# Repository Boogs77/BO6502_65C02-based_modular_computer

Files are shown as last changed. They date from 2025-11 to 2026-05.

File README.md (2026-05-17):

# BO6502: 65C02-Based Modular Computer System






Technical overview of the **BO6502** core architecture. This system leverages the iconic 6502 instruction set with modern, high-reliability components from Western Design Center, Atmel, and Hitachi, offering a versatile platform for retro-computing enthusiasts.

---

## 🧠 Processing Core & System Control

The system is built around a modular 39-pin bus (36 signals + 3 spares) distributed via a robust backplane.

| Module | Type | Status | Description |
| :--- | :--- | :--- | :--- |
| **[CPU Module](https://github.com/Boogs77/BO6502/tree/main/BO6502%20CPU)** |  |  | Central Processing Unit W65C02S. |
| **[Reset & Clock](https://github.com/Boogs77/BO6502/tree/main/BO6502%20RESET)** |  |  | NE555 Reset and switchable clock (2MHz/1MHz/500kHz). |
| **[Backplate](https://github.com/Boogs77/BO6502/tree/main/BO6502%20BACKPLATE)** |  |  | The 39-pin bus backbone with voltage regulation. |
| **[Bridge Connector](https://github.com/Boogs77/BO6502/tree/main/BO6502%20CONNECTOR)** |  |  | Interconnect for daisy-chaining multiple backplates. |

---

## 💾 Memory Map & Storage

The system features a balanced 64KB memory architecture, divided between high-speed static RAM and non-volatile storage.

### [RAM Module](https://github.com/Boogs77/BO6502/tree/main/BO6502%20RAM) ($0000 - $7FFF)
* **Chip**: HITACHI **HM62256LP-12** (32KB SRAM).
* **Status**: 
* **Features**: Revision 02 includes **8 exclusion jumpers** (J-CS0 to J-CS7) to carve out space for I/O modules. Includes JP4 to bypass system clock triggering.
* **PCB**: [RAM_final_rev02](https://github.com/Boogs77/BO6502/blob/main/BO6502%20RAM/gallery/RAM_final_rev02.png?raw=true).

### [ROM Module](https://github.com/Boogs77/BO6502/tree/main/BO6502%20ROM) ($8000 - $FFFF)
* **Chip**: ATMEL **AT28C256** (32KB EEPROM).
* **Status**: 
* **Features**: Equipped with a **ZIF socket** for easy updates. The "Multi" version uses jumpers (J-CS3, CS4, CS5) to disable ROM in specific ranges for advanced peripherals.
* **PCBs**: [Base](https://github.com/Boogs77/BO6502_65C02-based_modular_computer/blob/main/BO6502%20ROM/gallery/ROM_final_rev01.png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) | [24K Test](https://github.com/Boogs77/BO6502_65C02-based_modular_computer/blob/main/BO6502%20ROM/gallery/ROM24k_final_rev01.png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) | [Multi-Selection](https://github.com/Boogs77/BO6502_65C02-based_modular_computer/blob/main/BO6502%20ROM/gallery/ROMmulti_final_rev01.png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).

---

## 🔌 Peripheral & I/O Addressing

Peripheral addressing is managed via **74LS138** decoders to ensure precise memory mapping and avoid bus contention.

| Module | Type | Status | Address | PCB Link |
| :--- | :--- | :--- | :--- | :--- |
| **[VDU Module](https://github.com/Boogs77/BO6502/tree/main/BO6502%20VDU)** |  |  | **$BXXX** | [VDU PCB](https://github.com/Boogs77/BO6502_65C02-based_modular_computer/blob/main/BO6502%20VDU/gallery/VDU_TMS_final_rev01.png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) |
| **[Serial I/O](https://github.com/Boogs77/BO6502/tree/main/BO6502%20SERIAL)** |  |  | **$CXXX** | [Serial PCB](https://github.com/Boogs77/BO6502_65C02-based_modular_computer/blob/main/BO6502%20SERIAL/gallery/Serial_final_rev03.png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) |
| **[SD Card](https://github.com/Boogs77/BO6502/tree/main/BO6502%20SDCard)** |  |  | **$D1BX** | [SD Card PCB](https://github.com/Boogs77/BO6502_65C02-based_modular_computer/blob/main/BO6502%20SDCard/gallery/SDcard_final_rev02%20v2.png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) |
| **[Standalone Keyb](https://github.com/Boogs77/BO6502/tree/main/BO6502%20KEYb)** |  |  | **$D18X** | [Keyboard PCB](https://github.com/Boogs77/BO6502/blob/main/BO6502%20KEYb/gallery/KEYb_final-rev01.png?raw=true) |
| **[Big LCD Module](https://github.com/Boogs77/BO6502/tree/main/BO6502%20BIGLCD)** |  |  | **$D19X** | [Big LCD Module](https://github.com/Boogs77/BO6502/blob/main/BO6502%20BIGLCD/README.md) |
| **[Legacy LCD/Keyb](https://github.com/Boogs77/BO6502/tree/main/BO6502%20LCD_KEYb)** |  |  | **$DXXX** | [Legacy PCB](https://github.com/Boogs77/BO6502/blob/main/BO6502%20LCD_KEYb/gallery/LCD_KEYb_final_rev02.png?raw=true) |

---

## 📺 Visual Output Tiers

* **Pro**: **TMS9918A** VDU Module with 32KB dedicated RAM. Supports NTSC Composite Out, Sprites, and 16 Colors.
* **Advanced**: **Toshiba T6963** Graphical LCD (160x128 Pixels).
* **Basic**: **Hitachi HD44780U** 16x2 Character LCD.

---

## 🛠 Diagnostic & Testing Tools

| Module | Type | Status | Function | PCB Link |
| :--- | :--- | :--- | :--- | :--- |
| **[Monitor Interface](https://github.com/Boogs77/BO6502/tree/main/BO6502%20MONITOR)** |  |  | Arduino Mega Bus Sniffer (Ben Eater style). | [Monitor PCB](https://github.com/Boogs77/BO6502/blob/main/BO6502%20MONITOR/gallery/MONITOR_final_rev01.png?raw=true) |
| **[LED Test Board](https://github.com/Boogs77/BO6502/tree/main/BO6502%20LED)** |  |  | Visual 16-LED debug for VIA 65C22 ports. | [LED PCB](https://github.com/Boogs77/BO6502/blob/main/BO6502%20LED/gallery/led_final.png?raw=true) |

---

## 📐 Important Technical Notes

### Jumper Configuration for Advanced Modules
When using the latest system modules (VDU, Joystick, SD Card, etc.), the **ROM** and **RAM** modules must be configured to prevent address conflicts:
- **ROM J-CS3/CS4/CS5**: Set to **VCC** to disable ROM in those specific I/O ranges.
- **SD Card Access**: Provides **Raw Data Access** via bit-banged SPI (PA1=MISO, PA2=MOSI, PA3=SCK, PA4=CS).

---
© 2026 Boogs77 | BO6502 Project - Technical Documentation.

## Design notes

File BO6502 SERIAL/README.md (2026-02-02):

# BO6502 Serial Interface





The **Serial Interface** module enables RS-232 communication for the BO6502 system. It allows the computer to connect to modern PCs (via serial-to-USB adapters) or vintage terminals, facilitating terminal-based interaction and data transfer.

---

## 🛠 Hardware Specifications

The module is designed around the classic 6502-family asynchronous communications interface adapter and standard voltage level shifters.

* **ACIA:** **W65C51** (Asynchronous Communications Interface Adapter), which handles the parallel-to-serial conversion.
* **Level Shifter:** **MAX232** integrated circuit, used to convert the TTL logic levels of the 65C51 to the RS-232 voltage standards required for external communication.
* **Connectivity:** Standard DB9 or pin-header configuration for serial TX/RX lines.

---

## 🕹️ Address Decoding ($CXXX)

The module uses a **74HCT138** 3-to-8 line decoder to map the serial controller into the system's I/O memory space.

* **Address Range:** The module is mapped to the **$CXXX** block.
* **Logic:** The decoder ensures that the ACIA chip select is triggered only when the CPU accesses the $C000 - $CFFF range. 

> [!NOTE]
> Ensure that no other I/O modules are configured to use the $CXXX page to avoid bus contention.

---

## 📐 Board Layout & Rendering

The Revision 03 design features improved signal routing for the high-voltage RS-232 lines and dedicated decoupling capacitors for the MAX232 charge pump to ensure stable communication at higher baud rates.

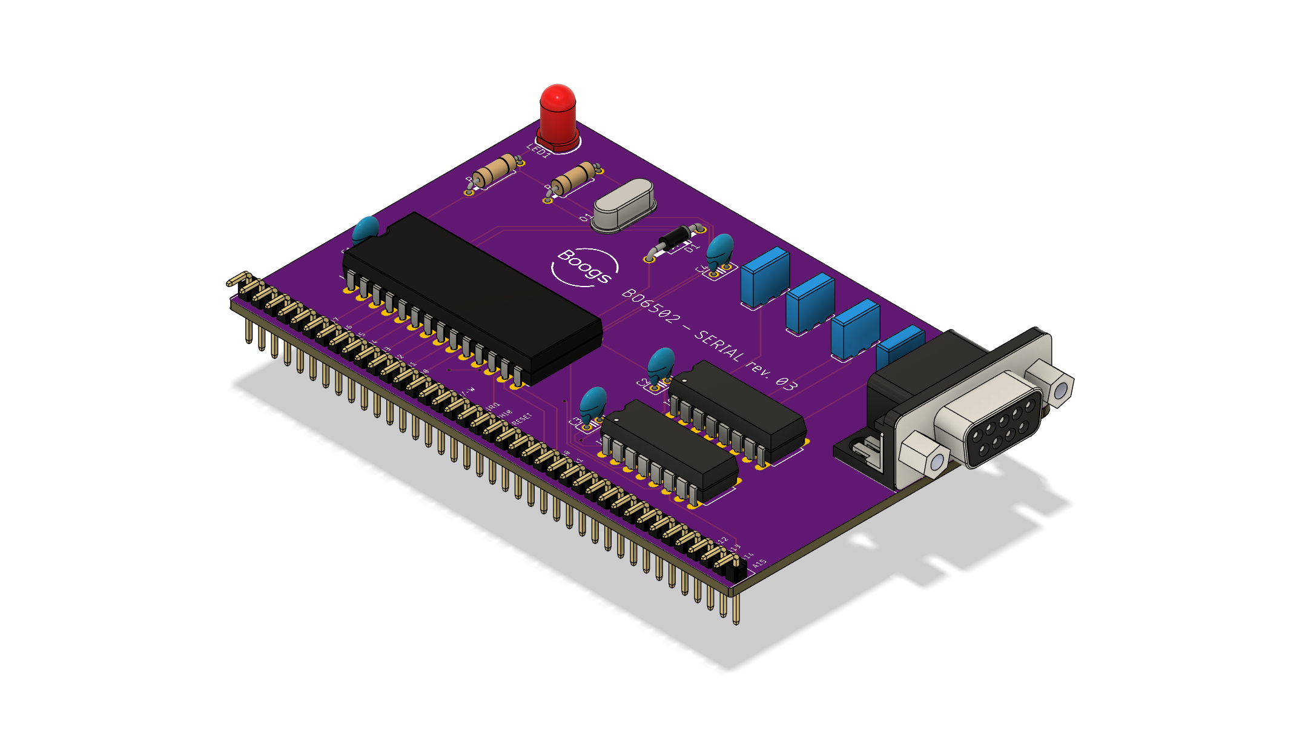
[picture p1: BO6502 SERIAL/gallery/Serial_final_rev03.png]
Hardware Rendering


---

## 🖥️ Programming Guide

To initialize the serial port, the software must configure the Control and Command registers of the W65C51 (typically at $C000-$C003).

1. **Set Baud Rate:** Configure the Control Register for the desired speed (e.g., 19200 bps).
2. **Parameters:** Set the Command Register for parity, echo, and interrupt requirements.
3. **Transmit/Receive:** Poll the Status Register bit to check if the Transmit Data Register is empty or if a byte has been received in the Receiver Data Register.

---

## 📂 Related Modules
* 🏗️ **[Backplate System](https://github.com/Boogs77/BO6502/blob/main/BO6502%20BACKPLATE/README.md)**: Main 39-pin system bus connection.
* 🧠 **[CPU Module](https://github.com/Boogs77/BO6502/blob/main/BO6502%20CPU/README.md)**: W65C02 central processor.
* 📜 **[ROM Module](https://github.com/Boogs77/BO6502/blob/main/BO6502%20ROM/README.md)**: Often contains the serial terminal driver or monitor.

---
© 2026 Boogs77 | BO6502 Project - Technical Documentation.

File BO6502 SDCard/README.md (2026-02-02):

# BO6502 SD Card Interface





The **SD Card Interface** provides the BO6502 system with bulk storage capabilities. This module is designed for direct, **raw data access** to SD cards, allowing the CPU to read and write sectors without the overhead of a complex file system layer.

---

## 🛠 Hardware Specifications

The module uses a **W65C22 VIA** to implement a software-controlled SPI (Serial Peripheral Interface) bus to communicate with the SD card.

* **Controller:** W65C22 Versatile Interface Adapter (VIA).
* **Storage Medium:** Standard SD/SDHC cards (3.3V Power Supply).
* **Data Access Mode:** **Raw Data Access only**. The system interacts directly with memory blocks on the card.
* **Voltage Level:** Integrated level shifting for **3.3V SD card** operation.

### SPI Pin Mapping (VIA Port A)
The SPI protocol is bit-banged using the following Port A pins:

| VIA Pin | Signal | Function |
| :--- | :--- | :--- |
| **PA1** | **MISO** | Master In Slave Out |
| **PA2** | **MOSI** | Master Out Slave In |
| **PA3** | **SCK** | Serial Clock |
| **PA4** | **CS** | Chip Select (Active Low) |

*Note: All other VIA pins not listed above are routed to pin strips for future development and expansion.*

---

## 🕹️ Address Decoding ($D1BX)

To ensure high compatibility with other system modules, this board features a precise decoding ladder using **three 74LS138** demultiplexers.

* **Address Range:** The module is mapped to the **$D1BX** range.
* **Logic:** The triple-138 configuration prevents address shadowing and ensures the module only responds when the $D1B0-$D1BF page is accessed.

---

## 📐 Board Layout & Rendering

The Revision 02 layout features a dedicated 3.3V regulator and optimized SPI signal paths to ensure data integrity during high-speed bit-banging.

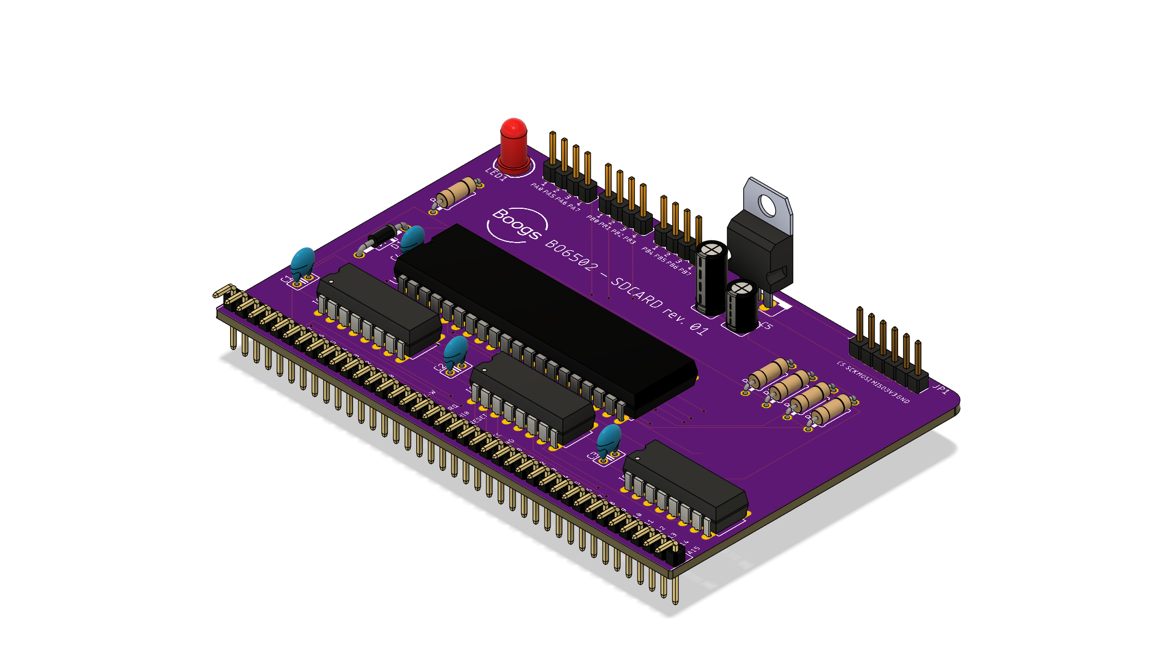
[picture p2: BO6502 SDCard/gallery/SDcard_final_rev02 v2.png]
Hardware Rendering


---

## 🖥️ Programming Guide

Since the interface provides **raw data access**, the user must implement the SPI initialization sequence (CMD0, CMD8, etc.) and block read/write routines in assembly.

1. **Initialize DDR:** Set PA2, PA3, and PA4 as outputs; PA1 as input.
2. **Bit-Banging:** Toggle PA3 (Clock) while shifting bits through PA2 (MOSI) and reading from PA1 (MISO).
3. **Sector Access:** Send raw SPI commands to access 512-byte blocks.

---

## 📂 Related Modules
* 🏗️ **[Backplate System](https://github.com/Boogs77/BO6502/blob/main/BO6502%20BACKPLATE/README.md)**: Main 39-pin system bus connection.
* 🧠 **[CPU Module](https://github.com/Boogs77/BO6502/blob/main/BO6502%20CPU/README.md)**: W65C02 central processor.
* 💾 **[RAM Module](https://github.com/Boogs77/BO6502/blob/main/BO6502%20RAM/README.md)**: Essential for buffering SD card sectors.

---
© 2026 Boogs77 | BO6502 Project - Technical Documentation.

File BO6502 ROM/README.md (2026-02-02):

# BO6502 ROM Module





The **ROM Module** provides non-volatile storage for the system BIOS, monitor, and kernel. It is based on the **AT28C256** (32KB EEPROM) and has undergone an evolutionary design process across three distinct phases to optimize memory mapping and peripheral compatibility.

---

## 🛠 Design Evolution

The development of this module followed three stages of evaluation to achieve the best integration with the BO6502 ecosystem:

### 1. ROM Base (Page Enable Version)
The initial prototype utilized a "Page Enable" logic for activation. After testing, this solution was discarded in favor of a more flexible decoding scheme.
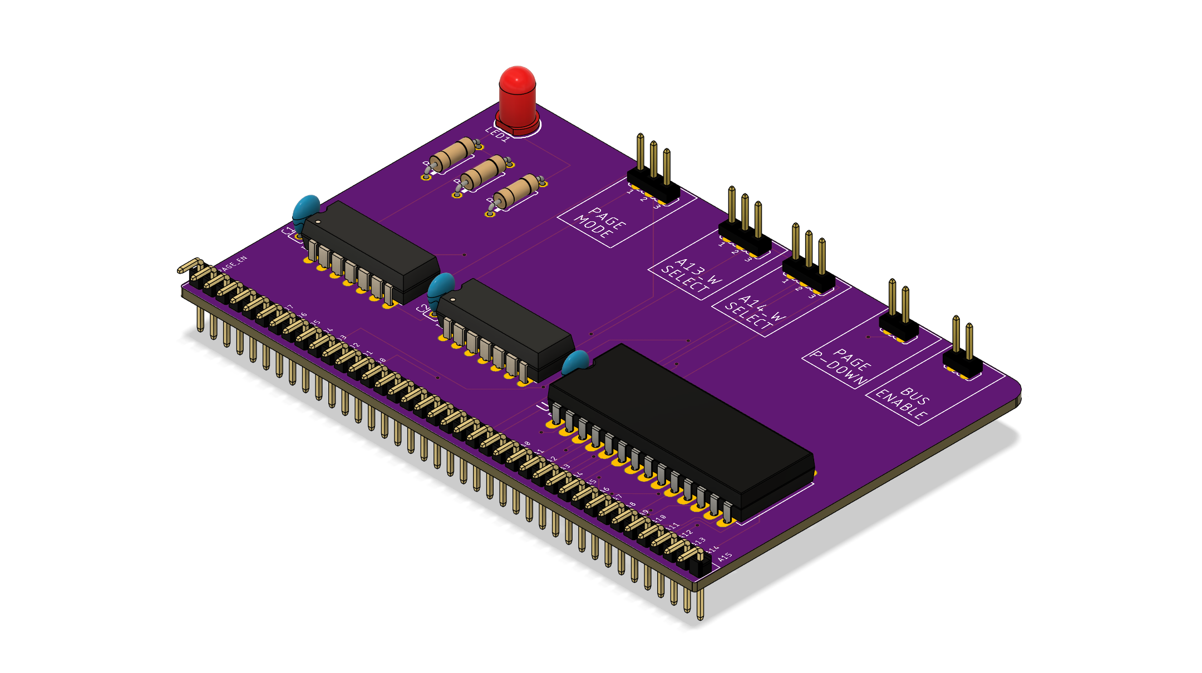
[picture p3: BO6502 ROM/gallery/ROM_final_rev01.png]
ROM Base


### 2. ROM Full 24K (Testing Phase)
A transitional version was created to utilize 24KB of the ROM. This board was primarily used for stress-testing the system's ability to handle larger firmware blocks before finalizing the hardware logic.
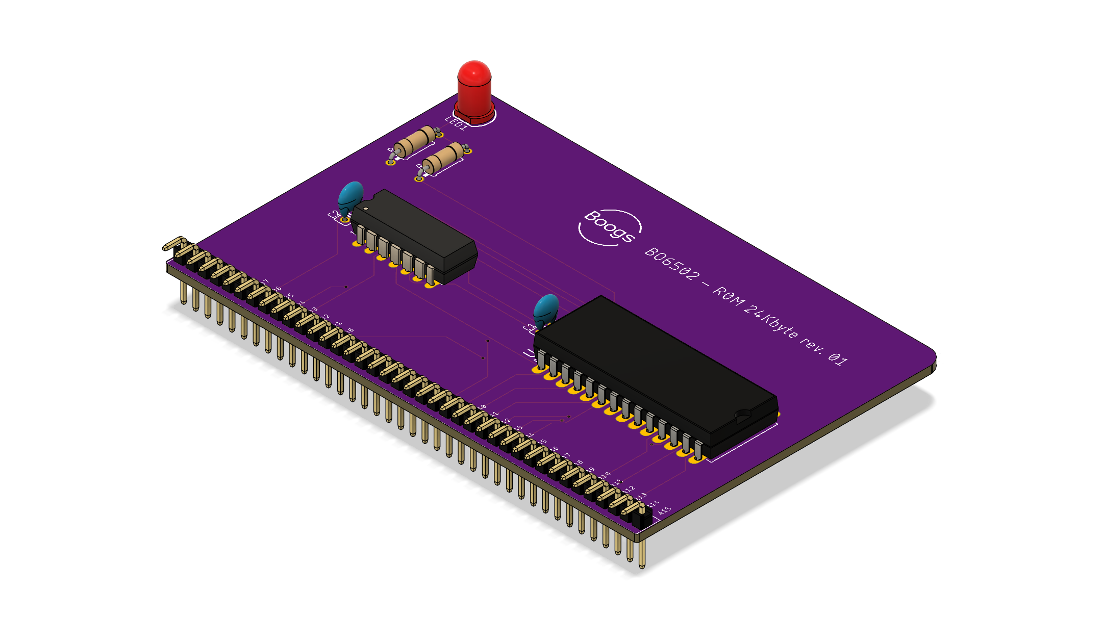
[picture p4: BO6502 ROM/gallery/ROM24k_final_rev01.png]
ROM 24K


### 3. ROM Multi (Configurable Jumper Version)
The final version adopts a highly versatile approach using **8 selection jumpers**, similar to the design choice made for the [RAM Module](https://github.com/Boogs77/BO6502/blob/main/BO6502%20RAM/README.md). This allows specific memory areas to be enabled or disabled to prevent bus contention with other I/O modules.
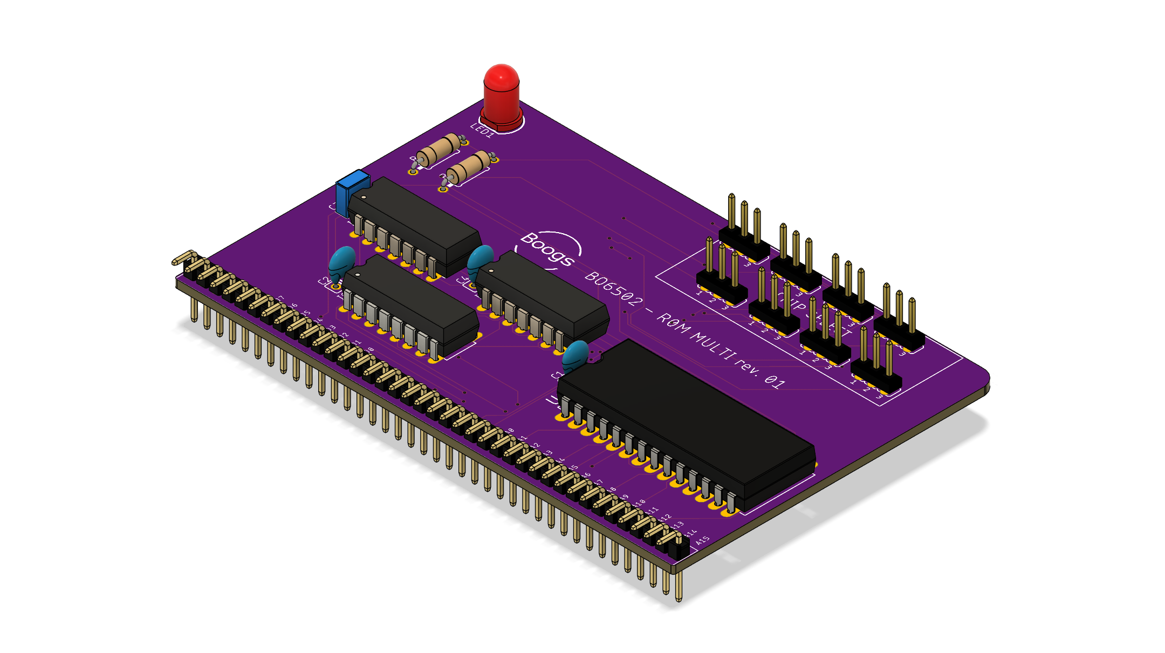
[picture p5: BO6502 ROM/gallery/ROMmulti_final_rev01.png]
ROM Multi


---

## 🕹️ Hardware Features & Configuration

### ZIF Socket
To facilitate frequent firmware updates and experimental testing, the production board is equipped with a **ZIF (Zero Insertion Force) socket**, allowing the EEPROM to be inserted and removed without mechanical stress.

### Jumper Settings for Advanced Modules
When using the latest system modules (VDU, Joystick, SD Card, and Audio), the following jumper configuration is required to ensure correct I/O mapping:

| Jumper | Setting | Function |
| :--- | :--- | :--- |
| **J-CS3** | **VCC** | Disables ROM in CS3 range |
| **J-CS4** | **VCC** | Disables ROM in CS4 range |
| **J-CS5** | **VCC** | Disables ROM in CS5 range |
| **Others** | **74138 Out** | Connected to the 74138 decoder outputs |

This configuration carves out the necessary address space for peripheral hardware while maintaining ROM availability for the rest of the high-memory area.

---

## 📂 Related Modules
* 🧠 **[CPU Module](https://github.com/Boogs77/BO6502/blob/main/BO6502%20CPU/README.md)**: Standard W65C02 system controller.
* 💾 **[RAM Module](https://github.com/Boogs77/BO6502/blob/main/BO6502%20RAM/README.md)**: Features the same jumper-based exclusion logic.
* 🏗️ **[Backplate System](https://github.com/Boogs77/BO6502/blob/main/BO6502%20BACKPLATE/README.md)**: Main 39-pin system bus.

---
© 2026 Boogs77 | BO6502 Project - Technical Documentation.

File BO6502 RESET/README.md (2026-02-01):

# BO6502 Reset & Clock Module





The **Reset & Clock Module** is a critical system utility for the BO6502. It provides a reliable power-on reset pulse and a flexible clock generation system to adapt the CPU speed to different hardware requirements.

---

## 🛠 Hardware Specifications

This module combines two essential system functions: power management and timing.

### Reset Circuitry
* **Logic:** Built around the classic **NE555** timer configured in monostable mode.
* **Function:** Ensures a clean and stable active-low RESET pulse upon power-up or manual trigger, ensuring the 65C02 CPU and peripherals initialize correctly.

### Clock Management & Scaling
The board features a flexible clock distribution system, allowing the user to select between different frequencies using a **74LS74** dual flip-flop for frequency division.

* **Direct 2 MHz Clock:** The system can be driven directly by a 2 MHz source (Note: the onboard clock on the CPU module must be disabled when using this configuration).
* **Scaled Frequencies:** Using the 7474 divider, the module can provide:
    * **1 MHz** (Division by 2).
    * **500 kHz** (Further division).
* **Selection:** This allows for high-speed operation or lower speeds for debugging and compatibility with older peripherals.

---

## 🕹️ Integration & Configuration

To use the external clock from this module, ensure the clock jumper/oscillator on the **BO6502 CPU Module** is disconnected to avoid bus contention.

| Frequency | Source / Logic | Recommended Use |
| :--- | :--- | :--- |
| **2 MHz** | Direct Bypass | Standard high-speed operation |
| **1 MHz** | 7474 Divider (Q1) | Standard 6502 compatibility |
| **500 kHz** | 7474 Divider (Q2) | Debugging / Slow peripheral testing |

---

## 📐 Board Layout & Rendering

The layout provides easy access to the reset button and features jumpers for quick frequency switching.

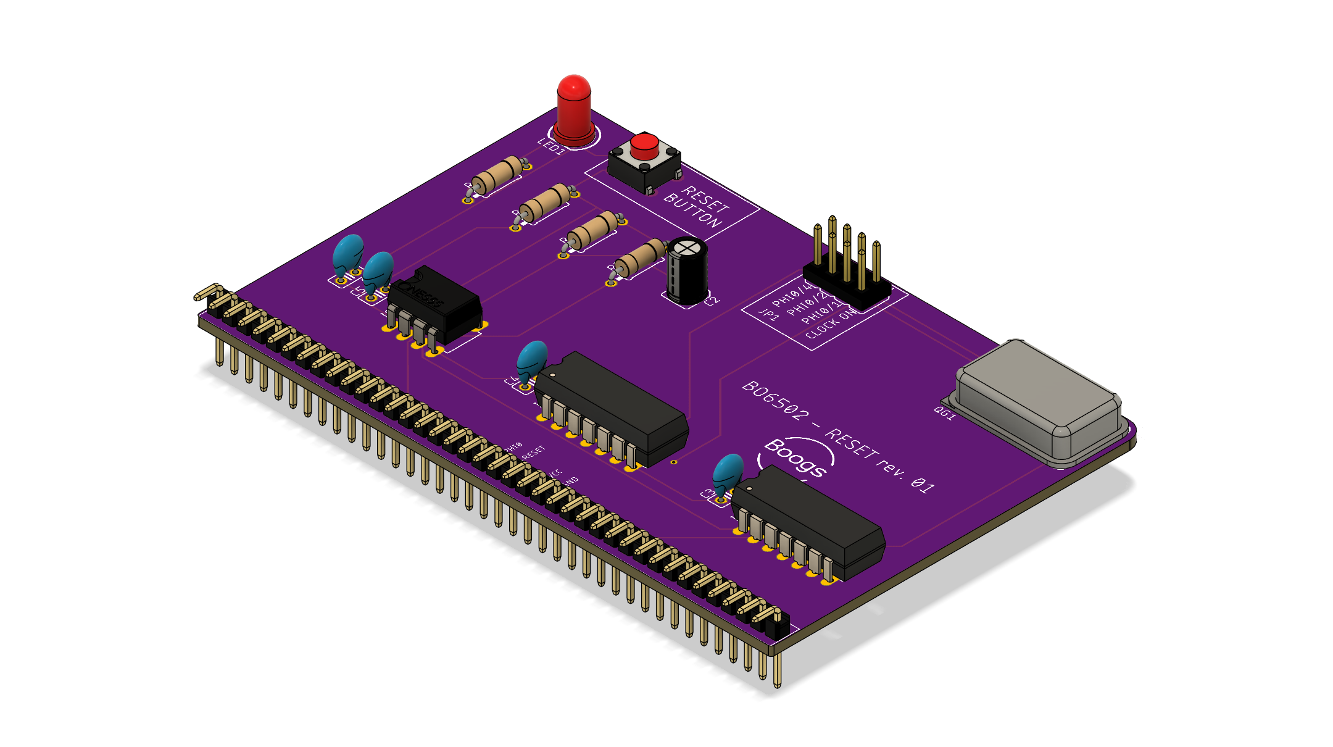
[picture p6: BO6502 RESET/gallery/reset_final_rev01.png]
Hardware Rendering


---

## 📂 Related Modules
* 🧠 **[CPU Module](https://github.com/Boogs77/BO6502/blob/main/BO6502%20CPU/README.md)**: W65C02 central processor (requires clock coordination).
* 🏗️ **[Backplate System](https://github.com/Boogs77/BO6502/blob/main/BO6502%20BACKPLATE/README.md)**: Distributes the Reset and Clock signals to all slots.
* 🖥️ **[Monitor Interface](https://github.com/Boogs77/BO6502/blob/main/BO6502%20MONITOR/README.md)**: Used to verify bus activity after a reset.

---
© 2026 Boogs77 | BO6502 Project - Technical Documentation.

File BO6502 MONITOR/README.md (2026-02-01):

# BO6502 Monitor Interface





The **Monitor Interface** is a diagnostic tool designed to provide real-time visibility into the internal operations of the BO6502 system. By interfacing an **Arduino Mega**, it allows the user to inspect the Address Bus and Data Bus during execution.

---

## 🛠 Operation & Hardware Setup

This module is specifically conceived for debugging at very low clock frequencies (manual pulsing or slow-stepping). It is designed to work in conjunction with an external clock source, such as the **[6502 Clock Module by dbuchewald](https://github.com/dbwald/6502/tree/master/Schematics/Clock_module)**.

* **Controller:** The board features a socket for an **Arduino Mega**, which acts as the logic analyzer.
* **Bus Monitoring:** It captures the state of the 16-bit Address Bus and the 8-bit Data Bus.
* **Triggering:** The monitoring logic is synchronized with the system clock signal connected to an Arduino interrupt pin.
* **Power Management:** A **dedicated jumper** has been included in the design. This allows the user to choose whether to power the Arduino Mega from the system bus or to isolate it when using an **external power source**, preventing potential power conflicts.

---

## 💻 Logic & Firmware

The monitoring principle follows the implementation popularized by **Ben Eater**. The firmware triggers a read cycle on every **rising edge** of the clock.

* **Firmware Reference:** **[6502-monitor.ino](https://eater.net/downloads/6502-monitor.ino)**.
* **Mechanism:** When the clock signal goes high, the Arduino triggers an interrupt service routine (ISR) to sample the address and data lines instantly, formatting the output for the Serial Monitor (Hexadecimal/Binary).

---

## 🕹️ Addressing & Compatibility

Since this module acts as a passive listener (sniffer) on the bus, it does not require a specific I/O address range (like $DXXX) and does not interfere with the system's memory mapping.

> [!IMPORTANT]
> This module is intended for **low-speed diagnostics only**. Due to the sampling latency of the Arduino Mega, it cannot monitor the bus accurately at the full 1MHz+ speeds of the 65C02.

---

## 📐 Board Layout & Rendering

The board provides clean routing for the 39-pin system bus directly to the Arduino Mega digital headers.

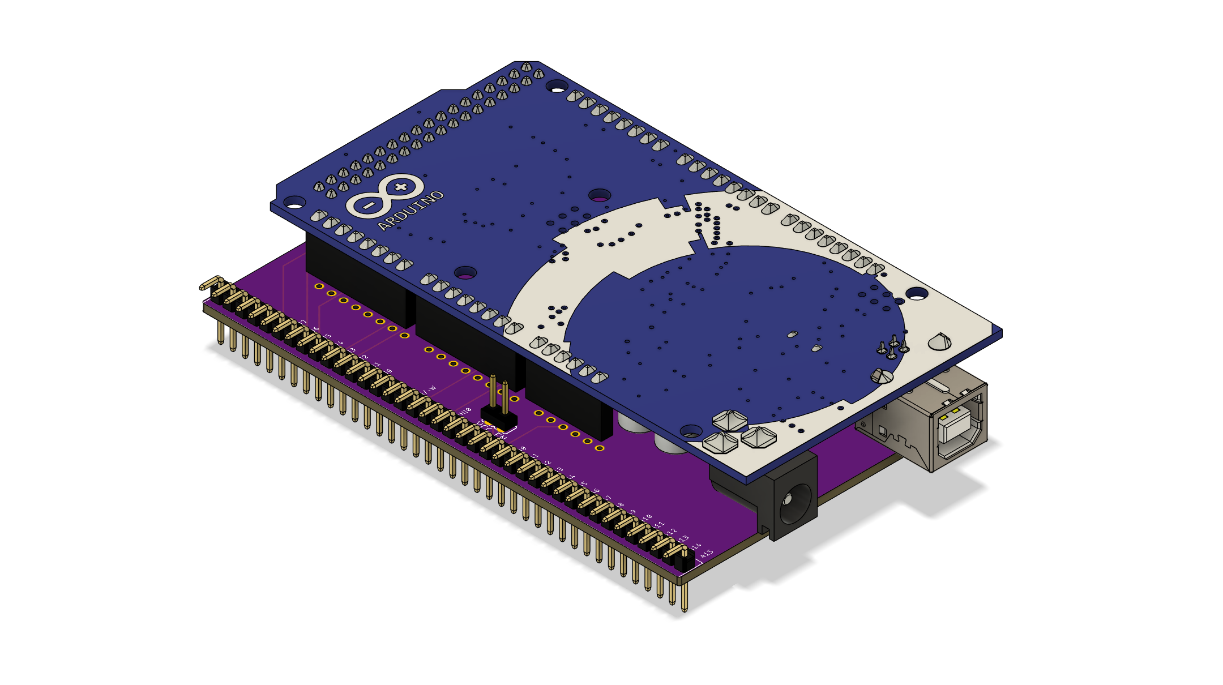
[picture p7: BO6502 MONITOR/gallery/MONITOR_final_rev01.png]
Hardware Rendering


---

## 📂 Related Modules
* 🏗️ **[Backplate System](https://github.com/Boogs77/BO6502/blob/main/BO6502%20BACKPLATE/README.md)**: Main 39-pin system bus connection.
* 🧠 **[CPU Module](https://github.com/Boogs77/BO6502/blob/main/BO6502%20CPU/README.md)**: W65C02 central processor.
* 🔴 **[LED Test Board](https://github.com/Boogs77/BO6502/blob/main/BO6502%20LED/README.md)**: Alternative visual diagnostic tool.

---
© 2026 Boogs77 | BO6502 Project - Technical Documentation.

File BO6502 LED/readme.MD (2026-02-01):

# BO6502 LED Test Board





The **LED Test Board** is a specialized diagnostic module designed to verify the operational functionality of the **W65C22 VIA** (Versatile Interface Adapter) and to monitor bus activity through visual feedback.

---

## 🛠 Hardware Specifications

This board serves as a hardware debugger and training tool for the BO6502 system. It allows for real-time visualization of the VIA port states.

* **LED Array:** Features 16 independent LEDs connected directly to the VIA I/O ports.
* **Port Mapping:** * **Port A (PA0-PA7):** Controls the first bank of 8 LEDs.
    * **Port B (PB0-PB7):** Controls the second bank of 8 LEDs.
* **Purpose:** Ideal for testing bit-banging routines, interrupt handling, and basic I/O operations before deploying more complex modules.

---

## 🕹️ Addressing & Compatibility Warning ($DXXX)

The module utilizes a broad addressing scheme for the W65C22 VIA, mapping it across the **$DXXX** memory interval.

> [!CAUTION]
> **Compatibility Note:** Due to the partial address decoding (using the entire $DXXX range), this board is **not compatible** with many other configurations and modules in the BO6502 project that occupy specific sub-ranges within the same space. It is primarily intended for standalone testing or minimal system configurations.

---

## 📐 Board Layout & Rendering

The layout is optimized for visibility, with the LED banks clearly labeled to match the corresponding VIA pins.

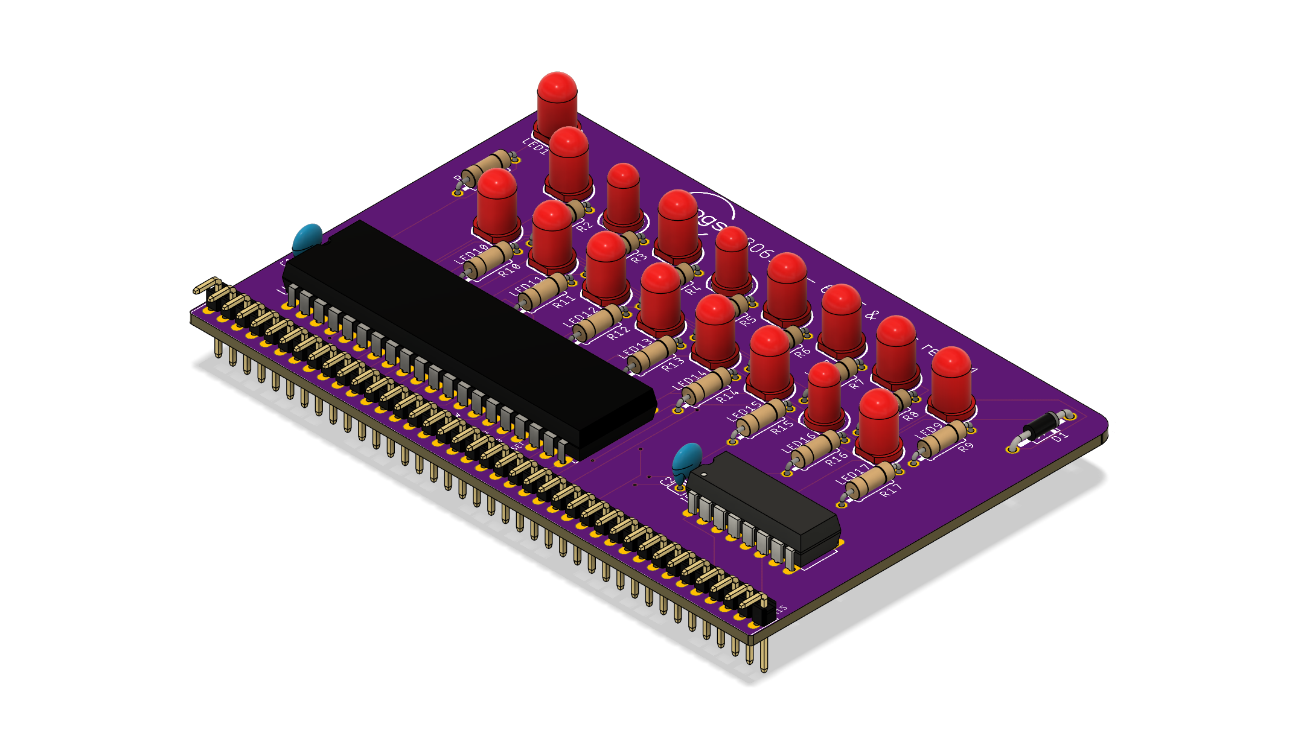
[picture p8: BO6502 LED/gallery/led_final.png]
Hardware Rendering


---

## 🖥️ Programming Guide

To light up the LEDs, the Data Direction Registers (DDR) must be configured as outputs.

```assembly
; BO6502 LED Test Code
LDA #$FF
STA $D002    ; Set DDRB as Output
STA $D003    ; Set DDRA as Output

LOOP:
    INC $D000 ; Increment Port B LEDs
    INC $D001 ; Increment Port A LEDs
    JMP LOOP

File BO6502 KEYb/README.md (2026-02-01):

# BO6502 Keyboard Interface





The **Standalone Keyboard Interface** is a dedicated input module for the BO6502 system. It was developed to isolate the keyboard logic from the legacy combined display module, ensuring better address space management and system stability.

---

## 🛠 Hardware Specifications

This module focuses exclusively on interfacing a vintage 5-pin DIN keyboard to the system bus using a **W65C22 VIA**.

* **Input Port:** Standard 5-pin DIN connector for AT/PS2-style keyboards.
* **Logic Architecture:** The keyboard clock (`KB_CLK`) and data (`KB_DATA`) signals are processed through **74HCT14N** Schmitt triggers to eliminate noise and ensure clean signal transitions.
* **Data Acquisition:** Employs two **74HCT595N** shift registers to convert the serial keyboard stream into a parallel format accessible by the VIA.

---

## 🕹️ Address Decoding & VIA Mapping ($D18X)

Unlike the legacy module, this board features a precise decoding scheme using **three 74LS138** demultiplexers to identify the **$D18X** address range.

| Register | Address | Specific Function |
| :--- | :--- | :--- |
| **ORA/IRA** | `$D181` | **Keyboard Data**: Input for parallel data bits (PA0-PA7). |
| **DDRA** | `$D183` | Port A Direction Register (Must be set to `$00` for input). |
| **CA1** | — | **KB_INT**: Handled via VIA interrupt control for new keystrokes. |

### Signal Distribution
* **PA0 - PA7:** Dedicated to the parallel output of the shift registers, allowing the CPU to read a full byte for each keystroke.
* **Decoding Logic:** The triple 74138 configuration ensures the module only responds to the specific **$D18X** page, preventing the broad address conflicts found in the previous combined version.

---

## 📐 Board Layout & Rendering

The revision 01 layout provides a streamlined path from the DIN connector to the shift registers, minimizing signal latency and interference.

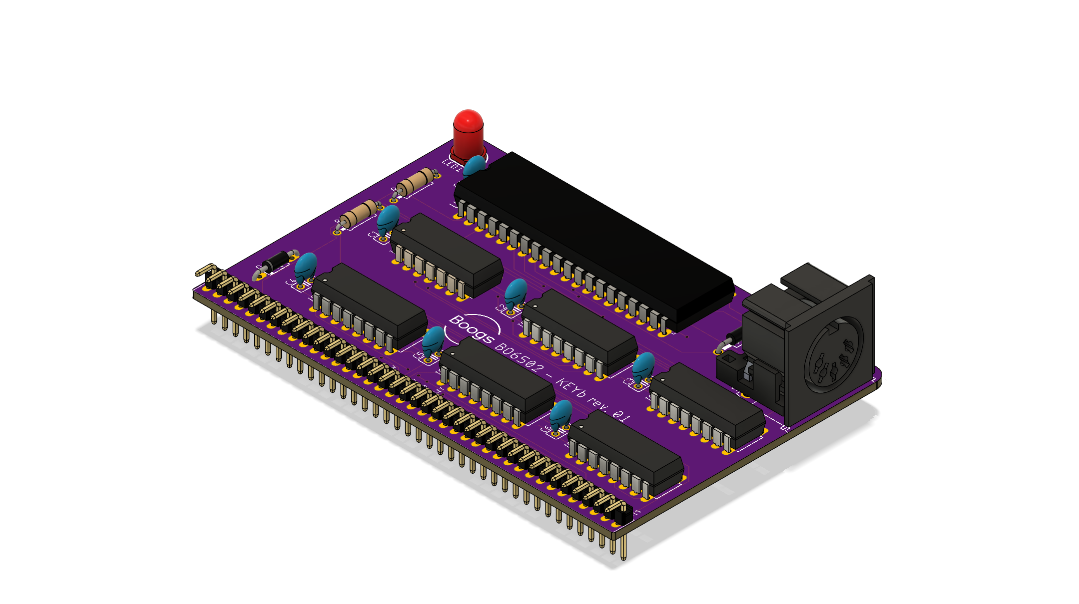
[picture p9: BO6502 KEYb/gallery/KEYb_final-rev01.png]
3D Rendering


---

## 🖥️ Programming Guide

The software should monitor the `KB_INT` signal. When a key is pressed, the shift registers populate the VIA's Port A.

1. **Initialization**: Set `DDRA` to `$00` to configure Port A as input.
2. **Interrupts**: Enable the `CA1` interrupt in the VIA to detect the keyboard's data-ready signal.
3. **Reading**: Upon interrupt, read the scan code directly from the Port A register at `$D181`.

---

## 📂 Related Modules
* 🏗️ **[Backplate System](https://github.com/Boogs77/BO6502/blob/main/BO6502%20BACKPLATE/README.md)**: 39-pin bus support.
* 🧠 **[CPU Module](https://github.com/Boogs77/BO6502/blob/main/BO6502%20CPU/README.md)**: W65C02 central processor.
* 📜 **[Legacy LCD & Keyboard Module](https://github.com/Boogs77/BO6502/blob/main/BO6502%20LCD_KEYb/README.md)**: The original combined module with $DXXX addressing.

---
© 2026 Boogs77 | BO6502 Project - Technical Documentation.

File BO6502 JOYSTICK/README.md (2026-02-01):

# BO6502 Joystick Interface





The **Joystick Interface** module brings classic gaming input capabilities to the BO6502 system. Designed for high compatibility and low-latency response, it allows the connection of iconic controllers from the 8-bit era.

---

## 🎮 Controller Compatibility

This module is specifically engineered to interface with **Sega Master System** (SMS) joysticks, utilizing the standard DB9 pinout. 

* **Interface:** Supports standard directional pads (Up, Down, Left, Right) and Action Buttons.
* **Logic:** Active-low signal handling, matching the original 8-bit console hardware standards.
* **Connectivity:** Standard DB9 Male connectors mounted on the PCB.

---

## 🛠 Hardware & Addressing

The module utilizes the versatile **W65C22 VIA** (Versatile Interface Adapter) to bridge the joystick signals to the 6502 data bus.

| Specification | Detail |
| :--- | :--- |
| **I/O Controller** | Western Design Center **W65C22 VIA** |
| **Memory Mapping** | Decoded at addresses **$D1AX** |
| **Bus Connector** | 39-pin (36 Active + 3 Spare) |
| **Power Supply** | +5V DC via Backplane |

### VIA 65C22 Register Mapping ($D1AX)

| Address | Register | Function |
| :--- | :--- | :--- |
| **$D1A0** | **ORB/IRB** | **Joystick 2**: Input Data (Directions & Buttons) |
| **$D1A1** | **ORA/IRA** | **Joystick 1**: Input Data (Directions & Buttons) |
| **$D1A2** | **DDRB** | Data Direction Register B (Set to `$00` for input) |
| **$D1A3** | **DDRA** | Data Direction Register A (Set to `$00` for input) |

---

## 🕹️ Signal Mapping (Sega Master System)

For both ports, a **bit value of 0** (Low) indicates the button is currently pressed.

| Bit | Signal | Port A ($D1A1) | Port B ($D1A0) |
| :--- | :--- | :--- | :--- |
| **0** | **UP** | Joystick 1 - Up | Joystick 2 - Up |
| **1** | **DOWN** | Joystick 1 - Down | Joystick 2 - Down |
| **2** | **LEFT** | Joystick 1 - Left | Joystick 2 - Left |
| **3** | **RIGHT** | Joystick 1 - Right | Joystick 2 - Right |
| **4** | **FIRE 1** | Joystick 1 - Button 1 | Joystick 2 - Button 1 |
| **5** | **FIRE 2** | Joystick 1 - Button 2 | Joystick 2 - Button 2 |

---

## 📐 Board Layout & Rendering

The revision 02 features an optimized trace routing to prevent signal ghosting and a compact form factor for easy installation.

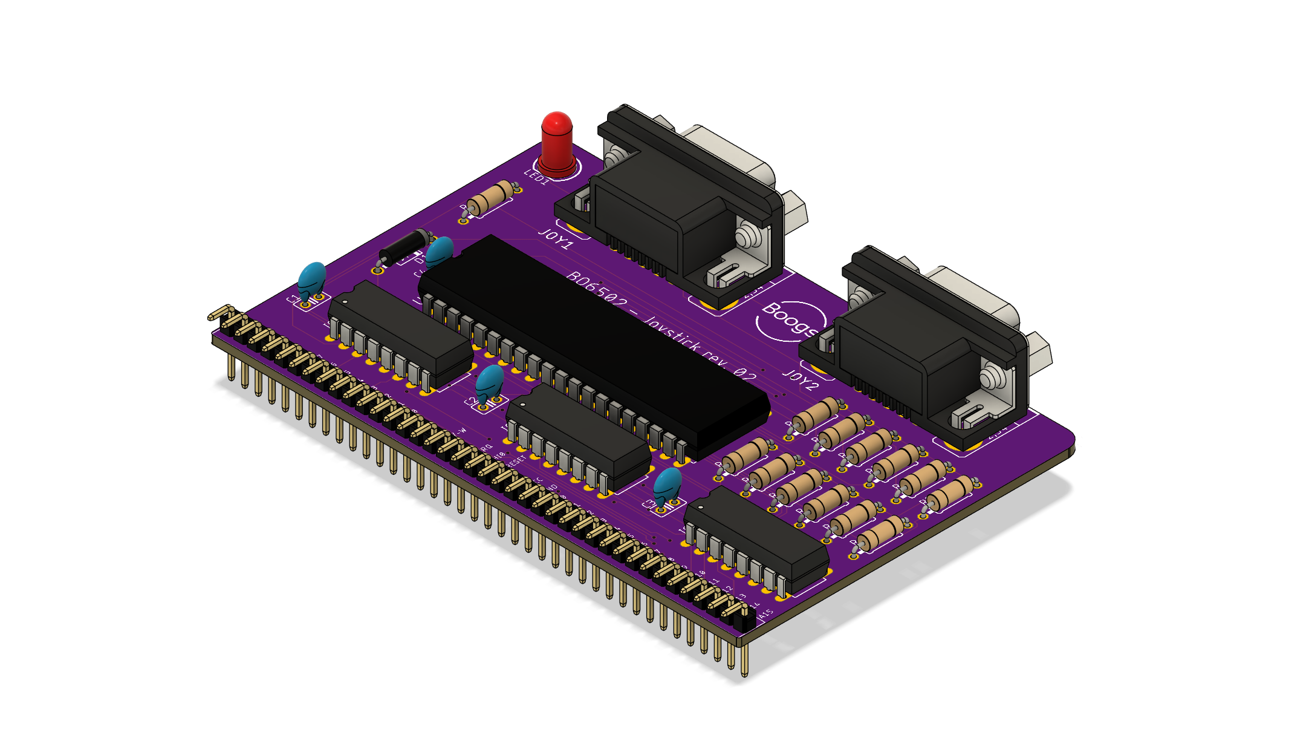
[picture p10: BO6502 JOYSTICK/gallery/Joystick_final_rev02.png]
3D Rendering


---

## 🖥️ Programming Guide

To read the joystick state, software must initialize the VIA Data Direction Registers (DDR) as inputs.

```assembly
; Example 6502 Initialization
LDA #$00
STA $D1A2    ; Set Port B as Input (Joystick 2)
STA $D1A3    ; Set Port A as Input (Joystick 1)

; Reading Joystick 1
LDA $D1A1    ; Read Port A status

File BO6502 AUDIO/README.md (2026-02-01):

# BO6502 Dual Sound Module






A powerful stereo sound expansion for the BO6502 system, featuring two **General Instrument AY-3-8910** Programmable Sound Generators (PSG). This module provides 6 analog channels, noise generation, and versatile envelope control.

> [!WARNING]  
> **Current Status: Prototype / In-Testing.** > The hardware has been manufactured, but comprehensive functional testing is currently underway to ensure signal stability and audio fidelity.

---

## 🎵 Audio Architecture

The board is designed with a true stereo configuration, utilizing two independent PSGs and dedicated amplification for each channel.

* **Sound Generators:** 2x AY-3-8910 (3 voices each, 6 voices total).
* **Amplification:** 2x **LM386** operational amplifiers configured for a **200x Gain**, ensuring robust output for speakers or headphones.
* **Output:** Stereo analog signals with independent Left/Right processing.

---

## 🕹️ Address Decoding & Control Logic

The module features a sophisticated decoding ladder using **four 74LS138** demultiplexers to map the chips into the system I/O space.

### Memory Mapping
* **Base Range:** Decoded at **$D1C0 - $D1CF**.
* **Logic:** The first three 74138 ICs identify the **$D1CX** range. The fourth 74138 handles chip selection and synchronization with the system **Clock (High Level)**.

### Register Selection (Bus Control)
The bus state is controlled directly via the Address Bus (A0-A2), with A3 held at 0:

| Signal | Routing | Function |
| :--- | :--- | :--- |
| **BC1** | Linked to **A0** | Bus Control 1 (Address/Data select) |
| **BC2** | Tied to **VCC** | Bus Control 2 (Always High) |
| **BDIR** | Linked to **A1** | Bus Direction (Read/Write select) |

### Stereo Selection (Chip Select)
The fourth 74138 uses **A2** to toggle between the two physical chips:
* **Left Channel (PSG 1):** Active when **A2 = 0**.
* **Right Channel (PSG 2):** Active when **A2 = 1**.

---

## 📐 Board Layout & Gallery

The layout manages high-frequency digital signals and analog audio traces with specific separation to minimize interference.

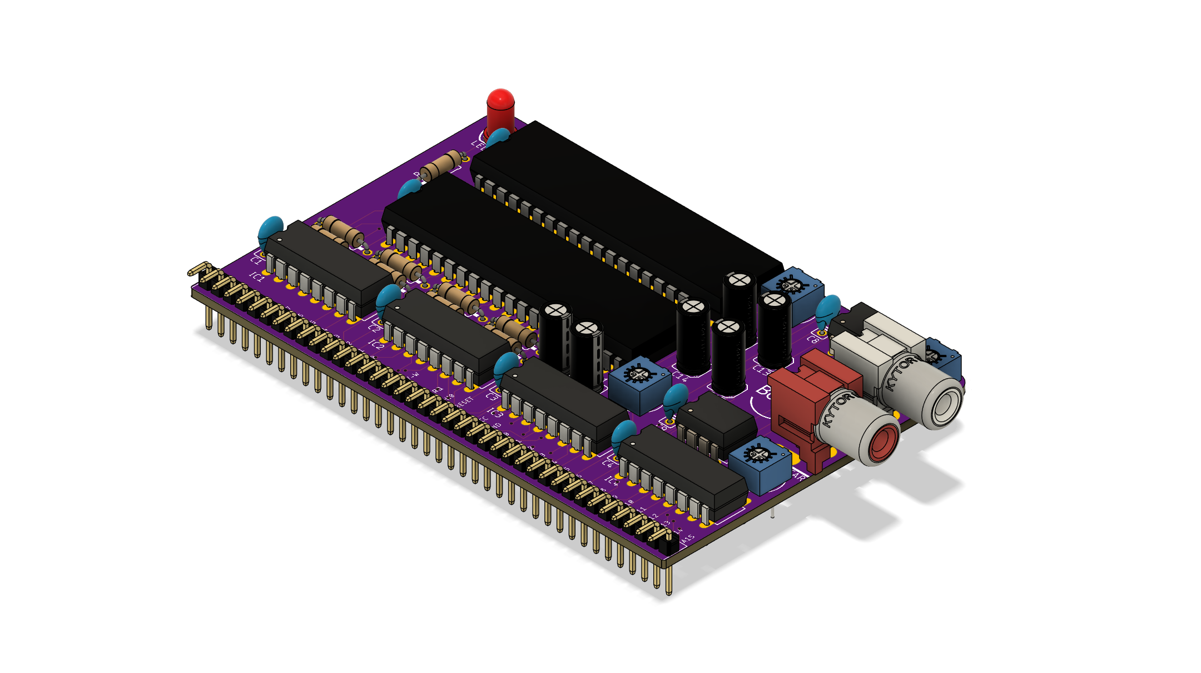
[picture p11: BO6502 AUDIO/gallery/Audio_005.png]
Hardware Gallery


---

## 📐 Technical Specifications

| Specification | Detail |
| :--- | :--- |
| **I/O Decoding** | 4x 74LS138 Logic |
| **Amplifier** | 2x LM386 (Gain 200) |
| **Bus Connector** | 39-pin (36 Active + 3 Spare) |
| **Clock Sync** | Synchronized with PHI2 High |

---

## 📂 Related Modules
* 🏗️ **[Backplate System](https://github.com/Boogs77/BO6502/blob/main/BO6502%20BACKPLATE/README.md)**: Main bus backbone.
* 🧠 **[CPU Module](https://github.com/Boogs77/BO6502/blob/main/BO6502%20CPU/README.md)**: System processing unit.
* 🕹️ **[Joystick Interface](https://github.com/Boogs77/BO6502/blob/main/BO6502%20JOYSTICK/README.md)**: Add gaming inputs to your audio.

---
© 2026 Boogs77 | Engineered for the 6502 enthusiast.

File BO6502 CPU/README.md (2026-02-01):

# BO6502 CPU Module





The heartbeat of the system. This module houses the **W65C02S** microprocessor and provides a flexible clock management system along with advanced signal routing via physical jumpers.

---

## 🧠 Core Processing Unit

At the center of this board is the **WDC W65C02S**, an enhanced CMOS version of the legendary 6502. 
* **Native Speed:** Integrated 1.0 MHz crystal oscillator.
* **Bus Integration:** Fully compatible with the 39-pin BO6502 backplane system (36 active pins + 3 spare).

---

## 🛠 Hardware Configuration (Jumper Settings)

The PCB features **5 dedicated Jumpers** to allow precise hardware-level control and legacy compatibility:

| Jumper | Function | Description |
| :--- | :--- | :--- |
| **CLK_EN** | **Enable Clock** | Connects the onboard oscillator to the CPU Φ2 input. |
| **PWR_CLK** | **Clock Power** | Allows isolating or de-powering the oscillator for external clock testing. |
| **IRQ_EN** | **Interrupt Request** | Enables/Disables the maskable interrupt line. |
| **NMI_EN** | **Non-Maskable Int.** | Enables/Disables the high-priority NMI signal. |
| **VP_COMP** | **Vector Pull / Legacy** | Manages the **VP** signal to maintain compatibility with original 6502 designs. |

---

## 📐 Board Layout & Rendering

The layout is optimized for signal integrity, with jumpers placed for easy access during hardware debugging.

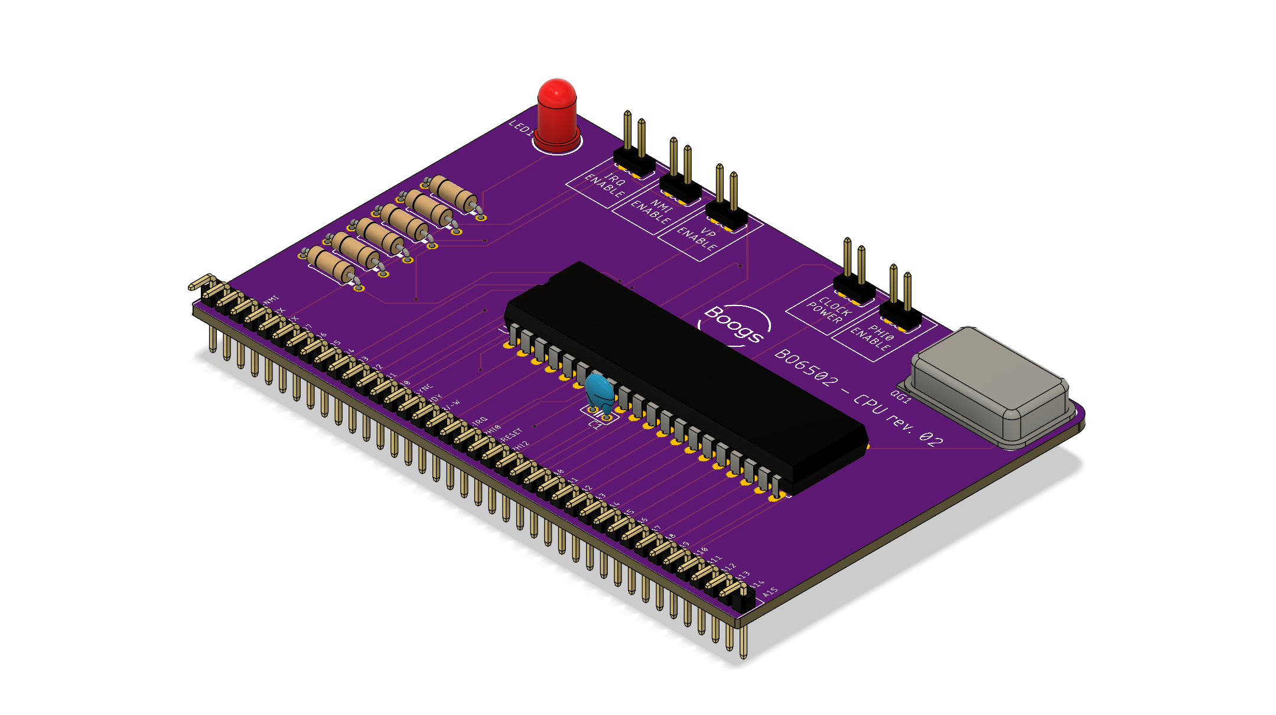
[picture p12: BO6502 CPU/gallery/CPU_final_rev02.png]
3D Rendering


---

## 📐 Technical Specifications

| Specification | Detail |
| :--- | :--- |
| **Processor** | Western Design Center W65C02S |
| **Primary Clock** | 1.0 MHz (Crystal Controlled) |
| **Bus Connector** | 39-pin (36 Active + 3 Spare) |
| **Logic Voltage** | +5V DC |

---

## 🔌 Legacy & Compatibility
The **VP_COMP** jumper is essential for projects requiring strict timing or hardware behavior identical to the original NMOS 6502. By toggling this, the module ensures that the **Vector Pull (VP)** signal is handled correctly, preventing bus contention or logic errors in legacy-sensitive applications.

---

## 📂 Related Modules
* 🏗️ **[Backplate System](https://github.com/Boogs77/BO6502/blob/main/BO6502%20BACKPLATE/README.md)**: Main communication bus.
* 🔌 **[Bridge Connector](https://github.com/Boogs77/BO6502/blob/main/BO6502%20CONNECTOR/README.md)**: Multi-backplate expansion.
* 🖼️ **[Big LCD Module](https://github.com/Boogs77/BO6502/blob/main/BO6502%20BIGLCD/README.md)**: Graphical interface module.

---
© 2026 Boogs77 | Engineered for the 6502 enthusiast.

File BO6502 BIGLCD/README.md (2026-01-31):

# BO6502 BIG LCD Module





The **BIG LCD** module is a high-performance video expansion board for the BO6502 system, enabling advanced graphical output via a large-format display.

---

## 🖥 Display Specifications

This module is specifically designed to drive the **DS-G160128STBWW** graphical LCD, providing a significant upgrade over standard character displays.

* **Resolution:** 160 x 128 Pixels.
* **Controller:** Integrated **Toshiba T6963** (Industry standard for graphical LC-displays).
* **Interface:** Controlled via the **W65C22 VIA** (Versatile Interface Adapter) for seamless CPU integration.
* **Connection:** Robust connection between the PCB and the LCD panel is handled via a dedicated **Flat Flex Cable (FFC)**.

---

## 🛠 Hardware & Addressing

The board follows the standard BO6502 form factor and is mapped into the system memory for direct CPU control.

| Specification | Detail |
| :--- | :--- |
| **Bus Connector** | 39-pin (36 Active + 3 Spare) |
| **Interface Logic** | 8-bit Parallel via VIA 6522 |
| **Memory Mapping** | The VIA is decoded at addresses **$D19X** |
| **Power Supply** | +5V DC (Logic) |
| **Revision** | Final Rev. 02 |

---

## 📐 Board Layout & Rendering

The module features an optimized layout to minimize signal noise between the VIA controller and the LCD driver.

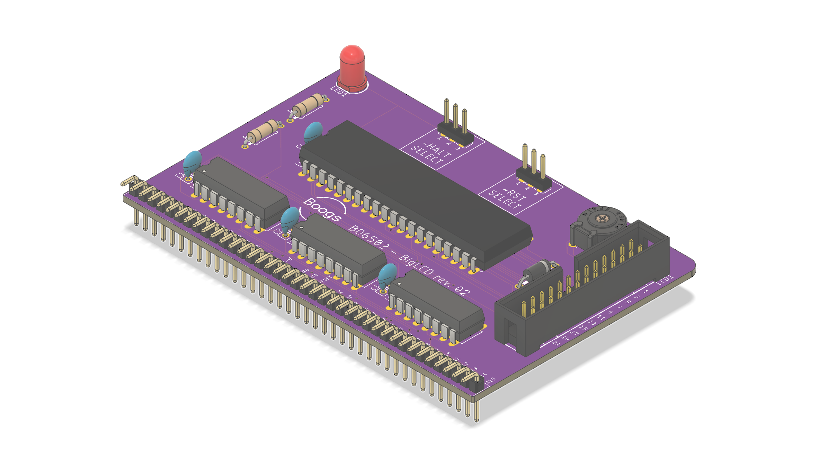
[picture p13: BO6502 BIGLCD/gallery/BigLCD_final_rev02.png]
3D Rendering


---

## 💡 Implementation Notes
* **Software Interfacing:** To communicate with the display, initialize the VIA registers starting at base address **$D190**.
* **Contrast Adjustment:** Check the onboard potentiometer (if present) to calibrate the display visibility for different viewing angles.

---
© 2026 Boogs77 | Part of the BO6502 Project ecosystem.

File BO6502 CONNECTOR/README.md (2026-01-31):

# BO6502 Bridge Connector





The **Bridge Connector** is a specialized linking module designed to daisy-chain multiple backplates, expanding the BO6502 bus capacity while maintaining signal integrity across the system.

---

## 🛠 Features & Functionality

This module facilitates a seamless connection between two backplates, ensuring that the Address, Data, and Control buses are synchronized.

### ⚡ Power Management Options
A key feature of this connector is its **Power Link Flexibility**:
* **Unified Power:** Jumpers/traces can be bridged to share a single power source across all connected backplates.
* **Isolated Power:** The power link can be disconnected, allowing each backplate to be powered by its own dedicated source—ideal for high-current setups or complex debugging.

---

## 📐 Technical Overview

| Specification | Detail |
| :--- | :--- |
| **Pin Count** | Full 39-pin Passthrough (36 Active + 3 Spare) |
| **Connection Type** | Board-to-Board Interconnect |
| **Power Isolation** | Supported via optional disconnection |

### Visual Preview
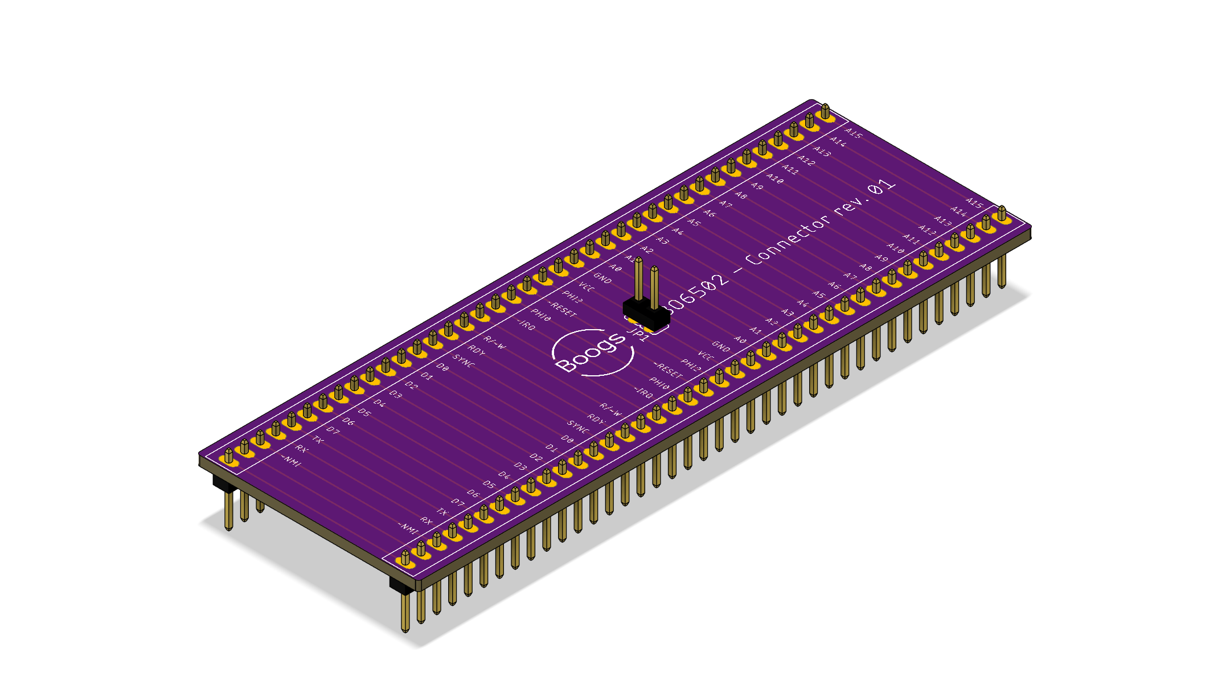
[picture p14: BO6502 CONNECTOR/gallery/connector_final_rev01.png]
3D Rendering


---

## 🔌 Best Practices
* **Signal Degradation:** When connecting more than two backplates, ensure your clock signal remains sharp (consider a bus buffer if necessary).
* **Isolation Mode:** Always ensure the power link is physically disconnected before applying two different power sources to the system to prevent backfeeding.

---
© 2026 Boogs77 | Part of the BO6502 Project ecosystem.

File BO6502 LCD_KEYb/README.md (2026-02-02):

# BO6502 LCD & Keyboard Interface


|  


The **LCD & Keyboard Interface** provides a complete user interface solution for the BO6502 system, integrating an alphanumeric display and support for vintage 5-pin DIN keyboards.

> [!CAUTION]
> **Compatibility Note:** This board utilizes a broad addressing range based on the **$DXXX** interval. Due to this wide decoding, the module may conflict with other peripherals in the project occupying the same memory space. Consequently, the keyboard section was later extracted into a dedicated standalone module.

---

## 🛠 Hardware Specifications

The module leverages the **W65C22 VIA** (Versatile Interface Adapter) to manage both the LCD output and the keyboard data acquisition.

* **LCD Display:** Interface for standard 16x2 modules (HD44780 controller) using pins **PB0-PB7** for the data bus.
* **Keyboard Interface:** 5-pin DIN input (X1) interfaced to VIA pins **PA0-PA1** via shift logic.
* **Acquisition Logic:** Dual **74HCT595N** shift registers handle the serialization of keyboard data, synchronized by the `KB_CLK` signal and cleaned through **74HCT14N** Schmitt triggers.

---

## 🕹️ VIA 65C22 Register Mapping ($DXXX)

The VIA registers are mapped into the I/O space to control the onboard peripherals:

| Register | Address (Base) | Specific Function |
| :--- | :--- | :--- |
| **ORB/IRB** | `$D000`* | **LCD Data Bus**: Sends data/instructions to the display (PB0-PB7) |
| **ORA/IRA** | `$D001`* | **Keyboard Interface**: Serial data acquisition (PA0-PA1) |
| **DDRB** | `$D002`* | Port B Direction Register (Set as Output for LCD) |
| **DDRA** | `$D003`* | Port A Direction Register (Set as Input for Keyboard) |

*\*Note: Address depends on the specific partial decoding of the $DXXX range.*

### Signal Details
* **PB0 - PB7:** Connected to LCD pins **DB0 - DB7** for character and command transfer.
* **PA0 - PA1:** Serial data reception from the 74HCT595 shift registers.
* **CA1:** Keyboard interrupt management (**KB_INT**) to signal the CPU when new data is available.

---

## 📐 Board Layout & Rendering

The design features an onboard potentiometer (R2) for display contrast adjustment (V0) and dedicated protection components for the keyboard input.

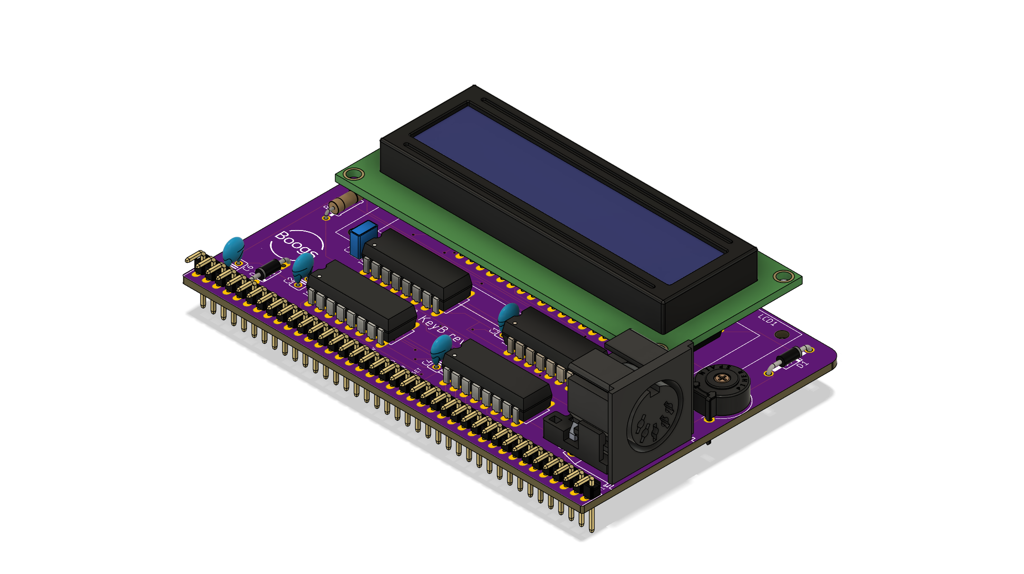
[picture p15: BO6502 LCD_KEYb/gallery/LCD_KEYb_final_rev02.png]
3D Rendering


---

## 📂 Related Modules
* 🏗️ **[Backplate System](https://github.com/Boogs77/BO6502/blob/main/BO6502%20BACKPLATE/README.md)**: 39-pin bus support.
* 🧠 **[CPU Module](https://github.com/Boogs77/BO6502/blob/main/BO6502%20CPU/README.md)**: W65C02 central processor.
* 🖼️ **[Big LCD Module](https://github.com/Boogs77/BO6502/blob/main/BO6502%20BIGLCD/README.md)**: High-resolution graphical alternative.

---
© 2026 Boogs77 | BO6502 Project - Technical Documentation.

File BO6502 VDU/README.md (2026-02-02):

# BO6502 VDU (Video Display Unit)





The **VDU Module** brings advanced color graphics and video capabilities to the BO6502 system. It is built around the legendary **TMS9918A** Video Display Processor (VDP), the same chip found in iconic systems like the MSX, ColecoVision, and TI-99/4A.

---

## 🛠 Hardware Specifications

The design of this module is the result of extensive research and optimization, integrating modern memory solutions with vintage video hardware.

* **Video Processor:** **TMS9918A** alowing for multiple video modes, including 15 colors plus transparent, and sprite support.
* **Video RAM:** Utilizes an **HM62256** (32KB SRAM) chip. Although the TMS9918A natively addresses 16KB, this modern SRAM provides a stable and reliable memory interface.
* **Logic Optimization:** Following the analysis of the **[HBC-56 project](https://github.com/visrealm/hbc-56/tree/main/schematics/tms9918)**, the design opts for a **74HCT245** transceiver instead of a third 74HCT574 latch. This choice streamlines the data bus communication between the CPU and the VDP.

### Design References
The architecture is heavily inspired by:
* **Leonardo Milani's work:** [Interfacing a TMS9918A to a 6502](https://www.leonardomiliani.com/?p=1631&lang=en).
* **J.B. Langston's design:** [TMS9918A Interface](https://github.com/jblang/TMS9918A).

---

## 🕹️ Address Decoding ($BXXX)

The module is integrated into the system memory map using a **74HCT138** decoder.

* **Address Range:** The VDU is mapped to the **$BXXX** block.
* **Interface:** The CPU communicates with the VDP via two specific addresses within this range to handle data transfers and register configurations.

---

## 📐 Development & Testing

Before the final PCB production, the board underwent rigorous testing:
* **Arduino Integration:** Extensive tests were performed using an **Arduino Mega** to verify the correct addressing logic and to validate all supported video modes (Text, Multicolour, Graphics I & II).
* **Signal Integrity:** Careful layout was implemented to ensure the composite video output remains clean and free from interference.

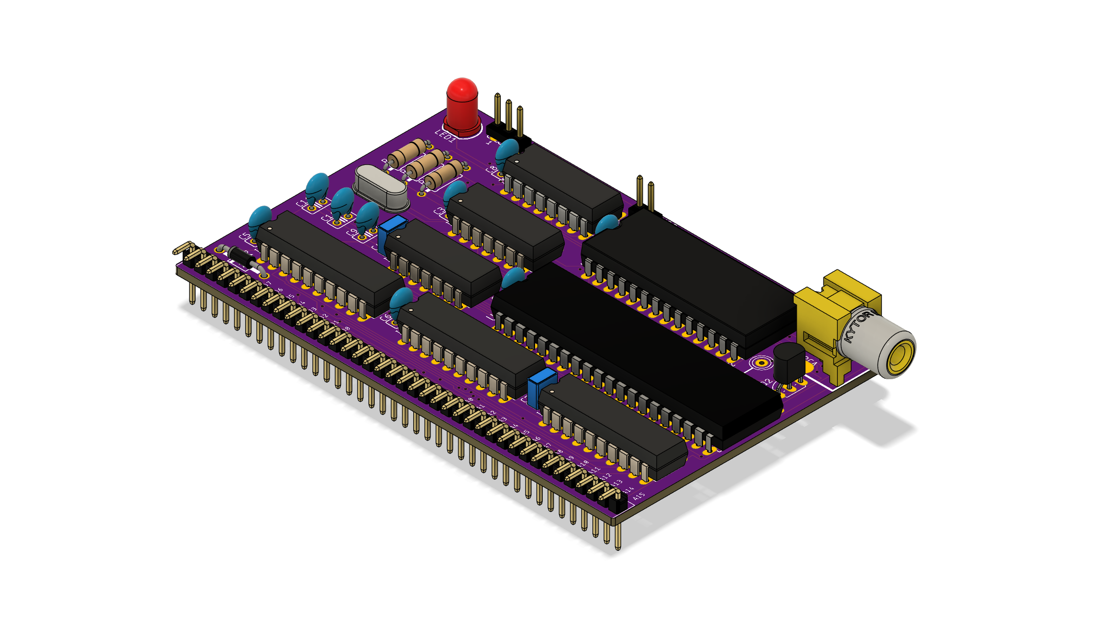
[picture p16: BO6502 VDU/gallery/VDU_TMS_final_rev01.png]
Hardware Rendering


---

## 📂 Related Modules
* 🏗️ **[Backplate System](https://github.com/Boogs77/BO6502/blob/main/BO6502%20BACKPLATE/README.md)**: Main 39-pin system bus connection.
* 🧠 **[CPU Module](https://github.com/Boogs77/BO6502/blob/main/BO6502%20CPU/README.md)**: W65C02 central processor.
* 🖥️ **[Monitor Interface](https://github.com/Boogs77/BO6502/blob/main/BO6502%20MONITOR/README.md)**: Used during early VDP register debugging.

---
© 2026 Boogs77 | BO6502 Project - Technical Documentation.

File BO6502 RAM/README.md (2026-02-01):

# BO6502 RAM Module





The **RAM Module** provides the primary volatile memory storage for the BO6502 system. This revision features a highly flexible addressing logic, allowing the user to map or exclude specific memory banks through a series of onboard jumpers.

---

## 🛠 Hardware Specifications

The module is designed to interface with the 6502 bus, providing fast access to 32KB of static RAM (SRAM).

* **Base Addressing:** By default, the module is mapped to the **$0000 - $7FFF** range. This is achieved by connecting the **A15** address line to the Enable pin of the decoder logic (active when A15 is Low).
* **Clock Synchronization:** The module typically triggers with the system clock to ensure data integrity during R/W cycles. However, **JP4** allows the user to set **IC2** as "Always Enabled," bypassing the system clock trigger for specific hardware configurations.

---

## 🕹️ Jumper Configuration & Memory Mapping

This module stands out for its versatility, managed through several jumper sets:

### I/O Exclusion Jumpers
The board includes **8 dedicated jumpers** designed to "carve out" space within the $0000 - $7FFF range. This allows other peripherals (such as I/O modules) to reside in that memory space without causing bus contention with the RAM.

### Address Bank Management
* **JP1 & JP2:** These jumpers allow the physical disconnection of **A13** and **A14** lines, useful for testing or specific memory mirroring configurations.
* **High-Memory Toggle:** A specific jumper configuration allows the RAM to be remapped to the **$8000 - $FFFF** range (High Memory) instead of its default Low Memory position.

---

## 📐 Board Layout & Rendering

The Revision 02 layout features optimized traces for high-speed signal integrity and clearly labeled jumper blocks for easy configuration.

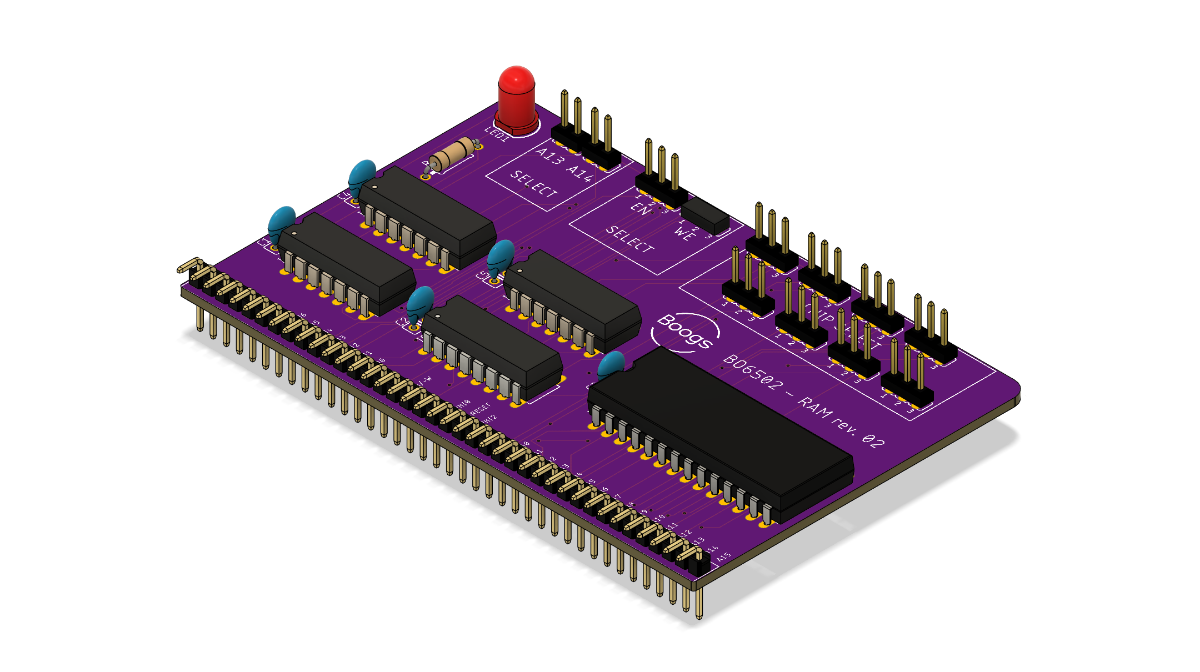
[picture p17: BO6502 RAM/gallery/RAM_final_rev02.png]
Hardware Rendering


---

## 📂 Related Modules
* 🏗️ **[Backplate System](https://github.com/Boogs77/BO6502/blob/main/BO6502%20BACKPLATE/README.md)**: 39-pin system bus connection.
* 🧠 **[CPU Module](https://github.com/Boogs77/BO6502/blob/main/BO6502%20CPU/README.md)**: W65C02 central processor.
* 🖥️ **[Monitor Interface](https://github.com/Boogs77/BO6502/blob/main/BO6502%20MONITOR/README.md)**: Recommended for debugging RAM read/write operations.

---
© 2026 Boogs77 | BO6502 Project - Technical Documentation.

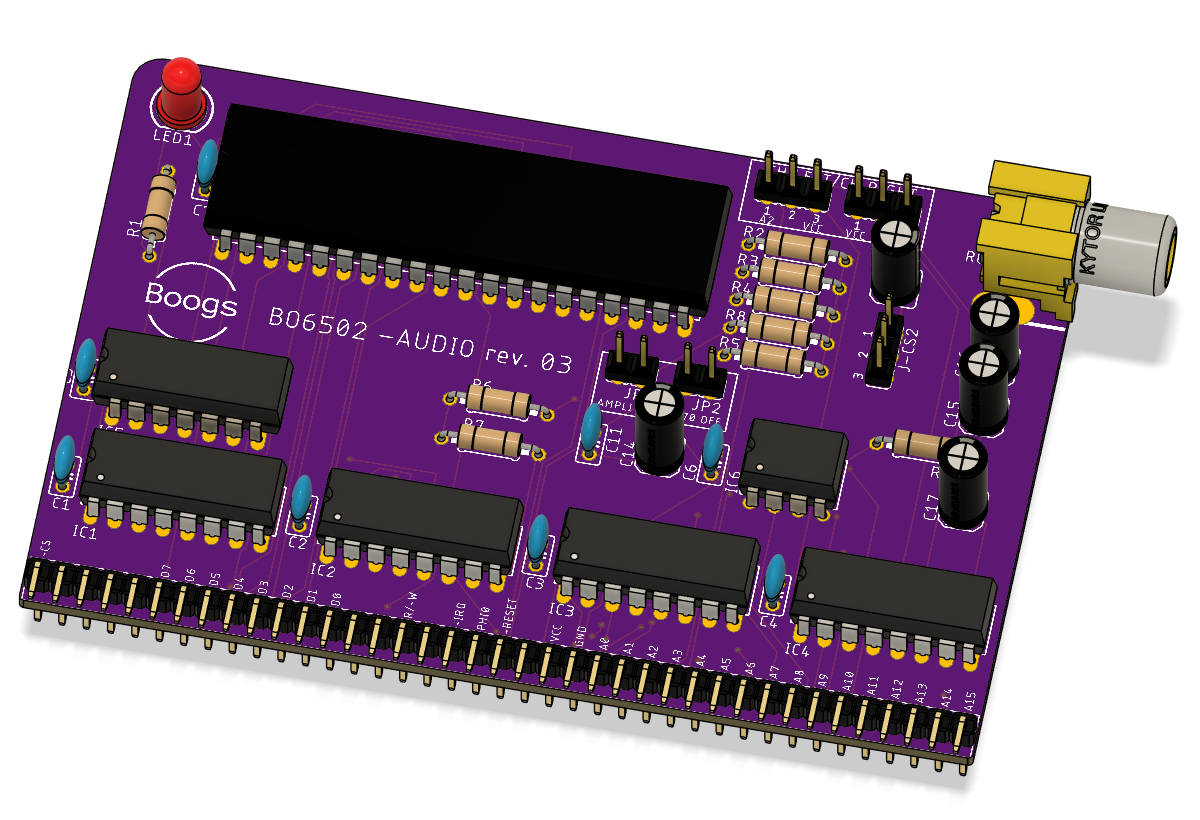
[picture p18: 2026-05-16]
BO6502 AUDIO/export/AUDIO_021.png

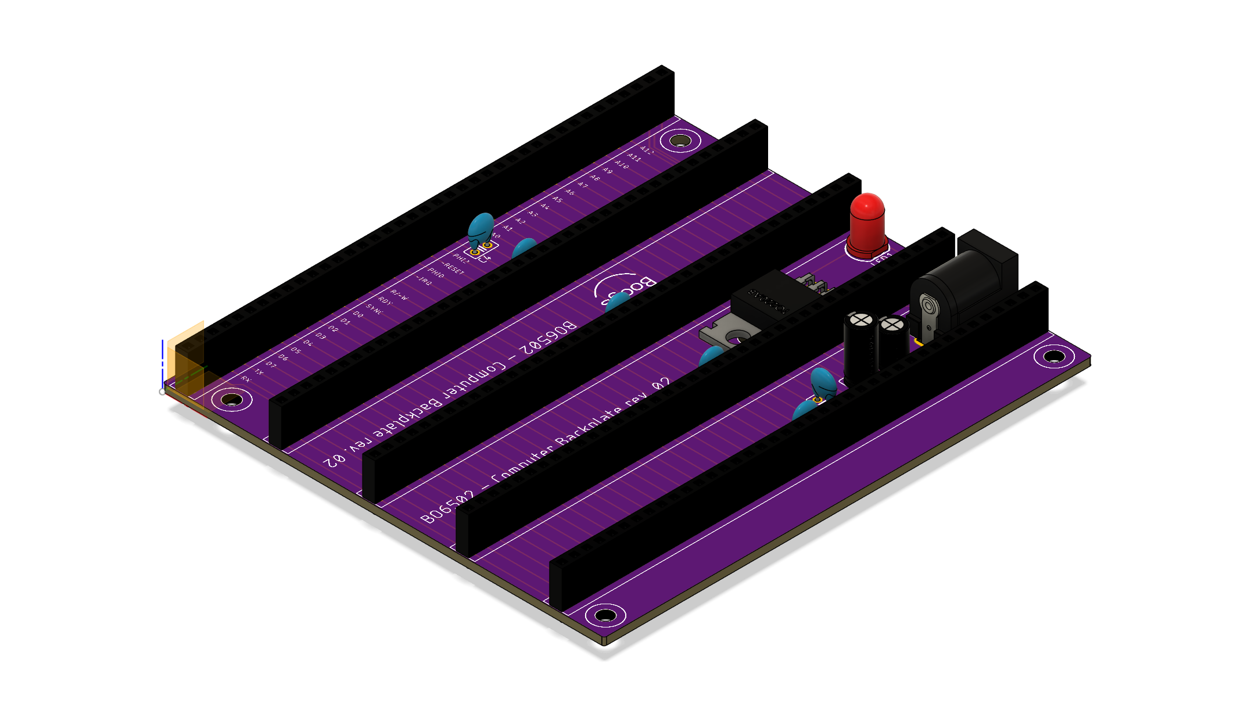
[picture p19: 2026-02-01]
BO6502 BACKPLATE/gallery/backplate_final_rev02.png

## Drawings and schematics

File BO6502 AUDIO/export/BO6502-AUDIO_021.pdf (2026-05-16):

Y7 | 7 Y6 | 9 Y5 | 10 Y4 | 11 Y3 | 12 Y2 | 13 Y1 | 14 Y0 | 15
IC6 | C¹⁵ R⁹ C¹⁷ | C16 GND VCC

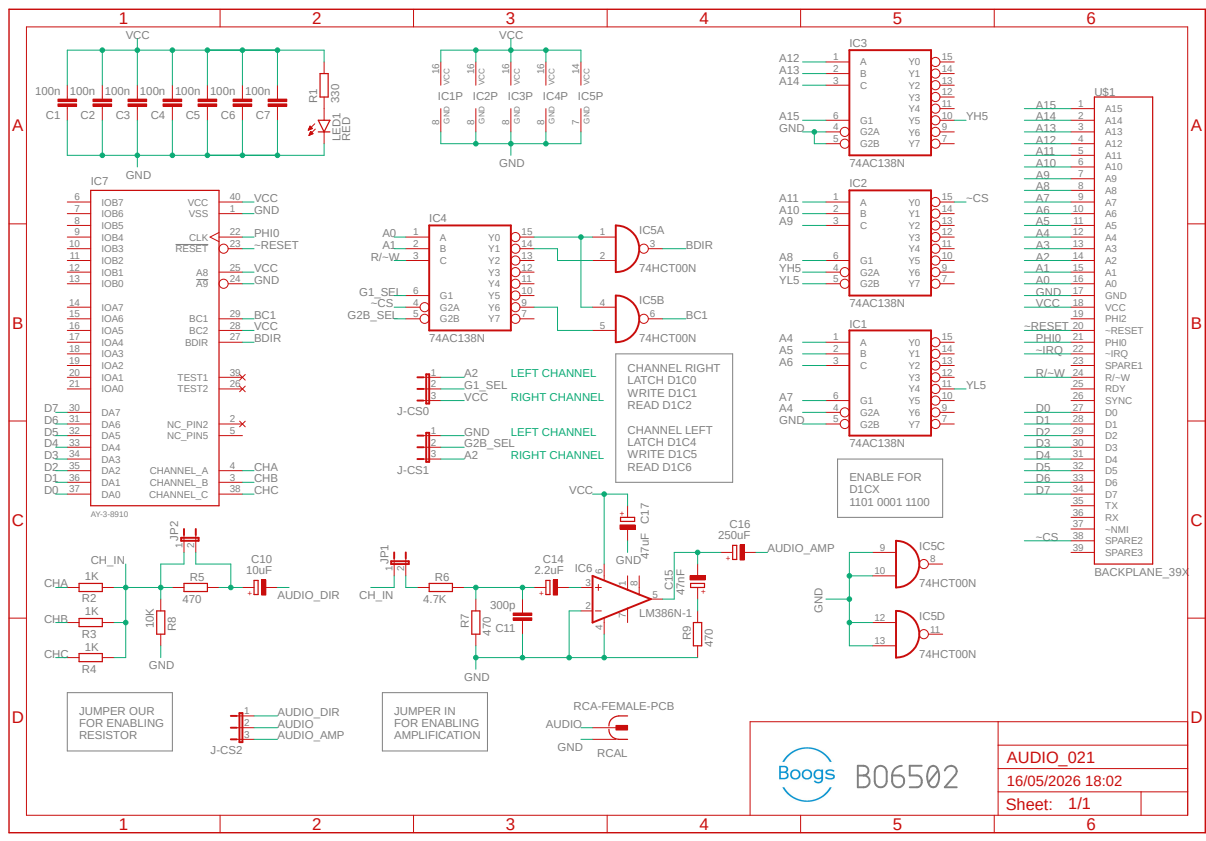
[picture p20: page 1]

VCC | VCC

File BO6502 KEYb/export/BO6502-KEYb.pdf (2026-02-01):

100n ¹N⁴¹⁴⁸ ⁷⁴HCT14N | 74HCT14N | 74HCT14N

A

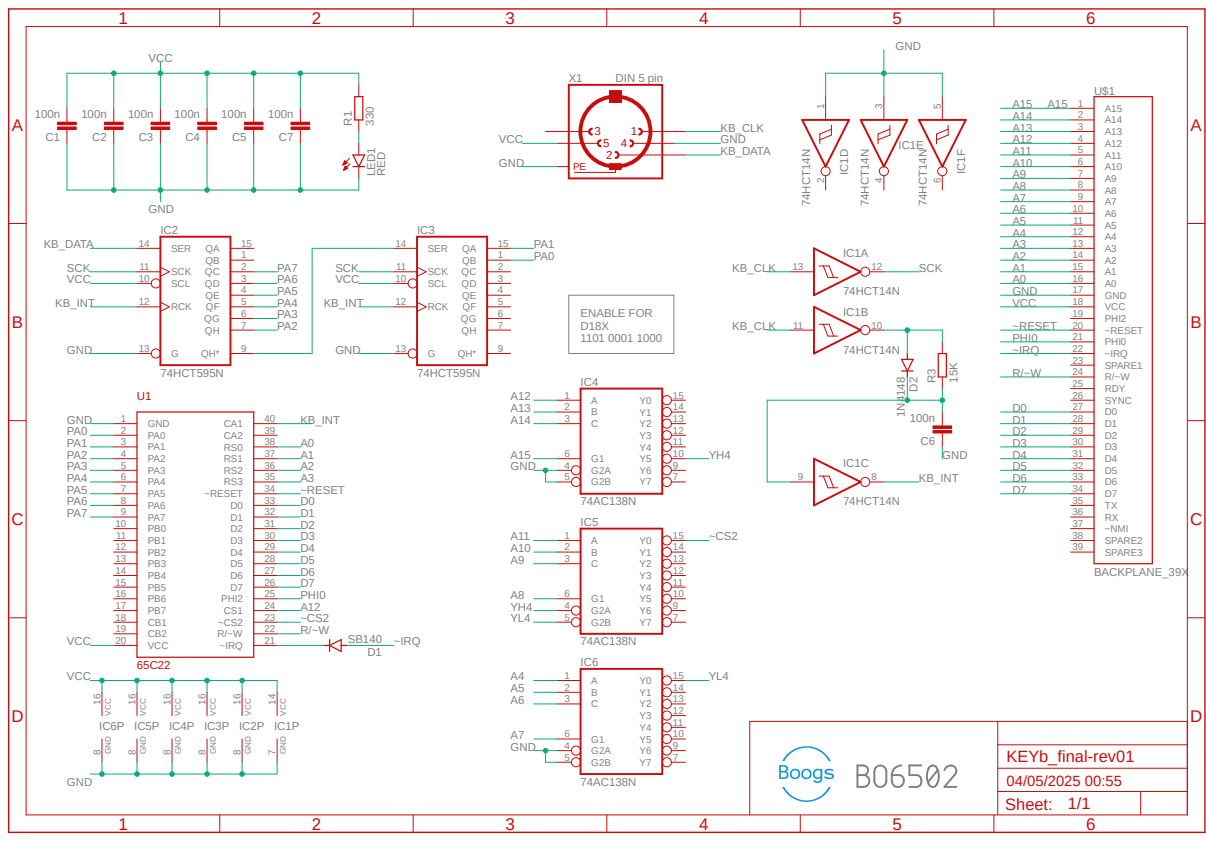
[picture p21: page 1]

GND

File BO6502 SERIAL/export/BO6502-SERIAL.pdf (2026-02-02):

A

A

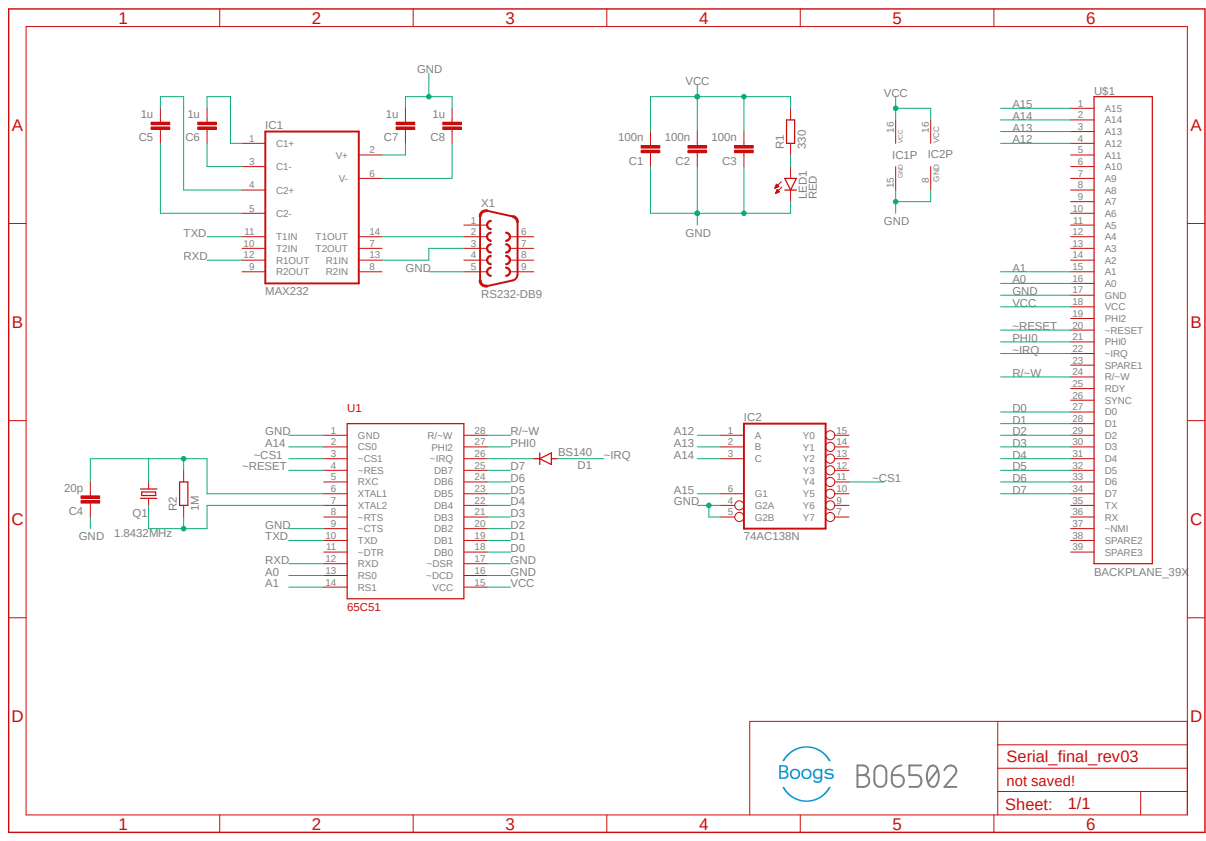
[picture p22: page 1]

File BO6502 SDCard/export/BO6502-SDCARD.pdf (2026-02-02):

Sheet: ABCD | 1 | 2 | 3 | 4 | 5 | 6 | ABCD 1 | 2 | 3 | 4 | 5 | 6

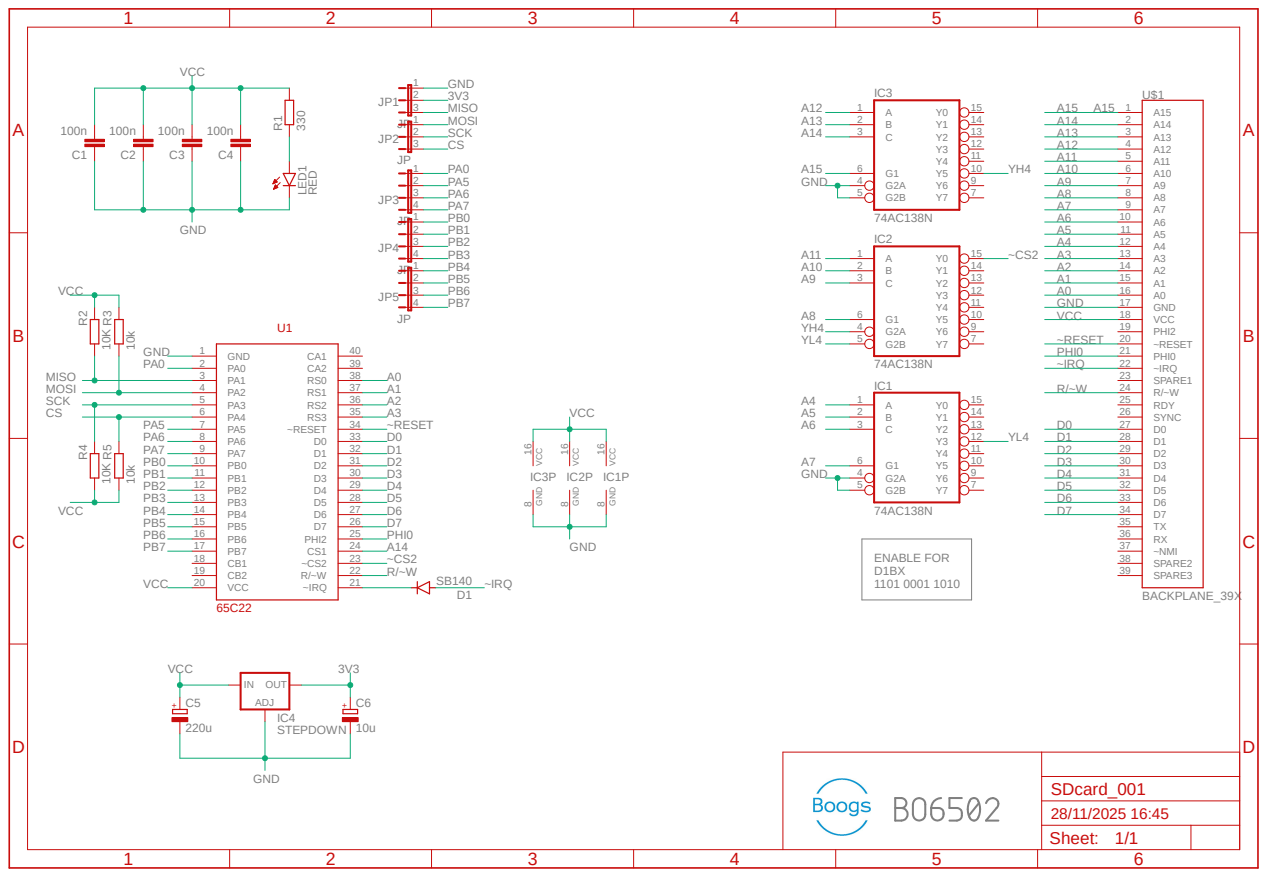
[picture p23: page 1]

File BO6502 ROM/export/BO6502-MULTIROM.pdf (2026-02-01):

A

A

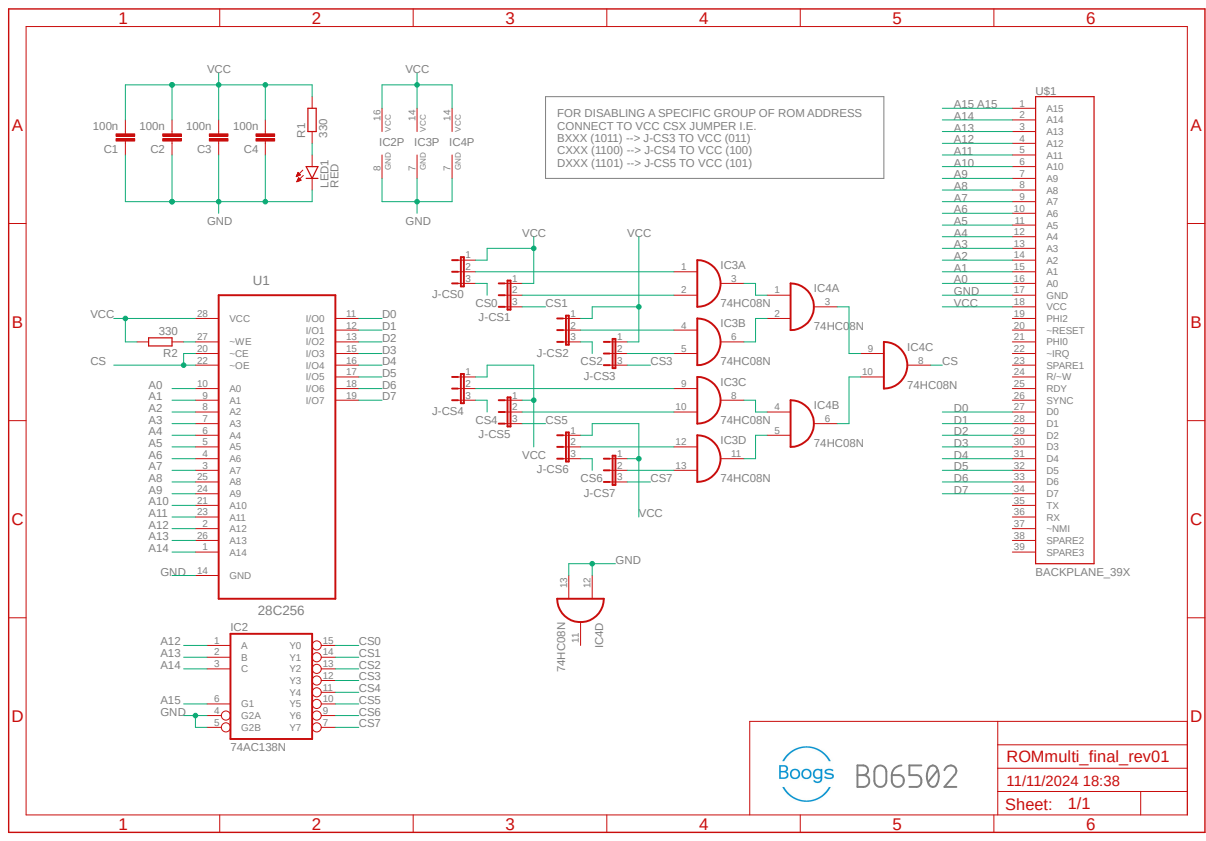
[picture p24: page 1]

FOR DISABLING A SPECIFIC GROUP OF ROM ADDRESS
CONNECT TO VCC CSX JUMPER I.E.
BXXX (1011) --> J-CS3 TO VCC (011)
CXXX (1100) --> J-CS4 TO VCC (100)
DXXX (1101) --> J-CS5 TO VCC (101)

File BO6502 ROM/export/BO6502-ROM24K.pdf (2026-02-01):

Sheet: ABCD | 1 | 2 | 3 | 4 | 5 | 6 | ABCD 1 | 2 | 3 | 4 | 5 | 6

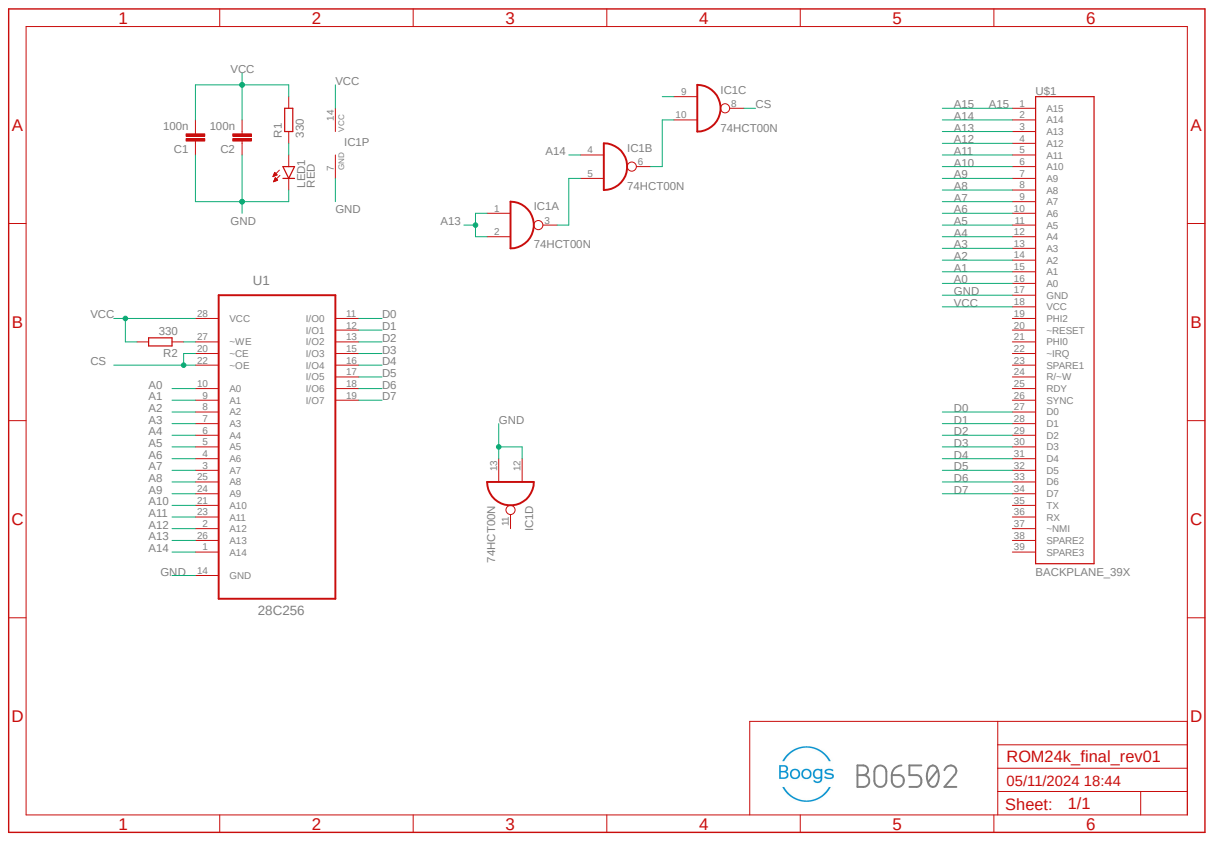
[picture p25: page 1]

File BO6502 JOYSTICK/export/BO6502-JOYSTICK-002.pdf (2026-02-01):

Sheet: ABCD | 1 | 2 | 3 | 4 | 5 | 6 | ABCD 1 | 2 | 3 | 4 | 5 | 6

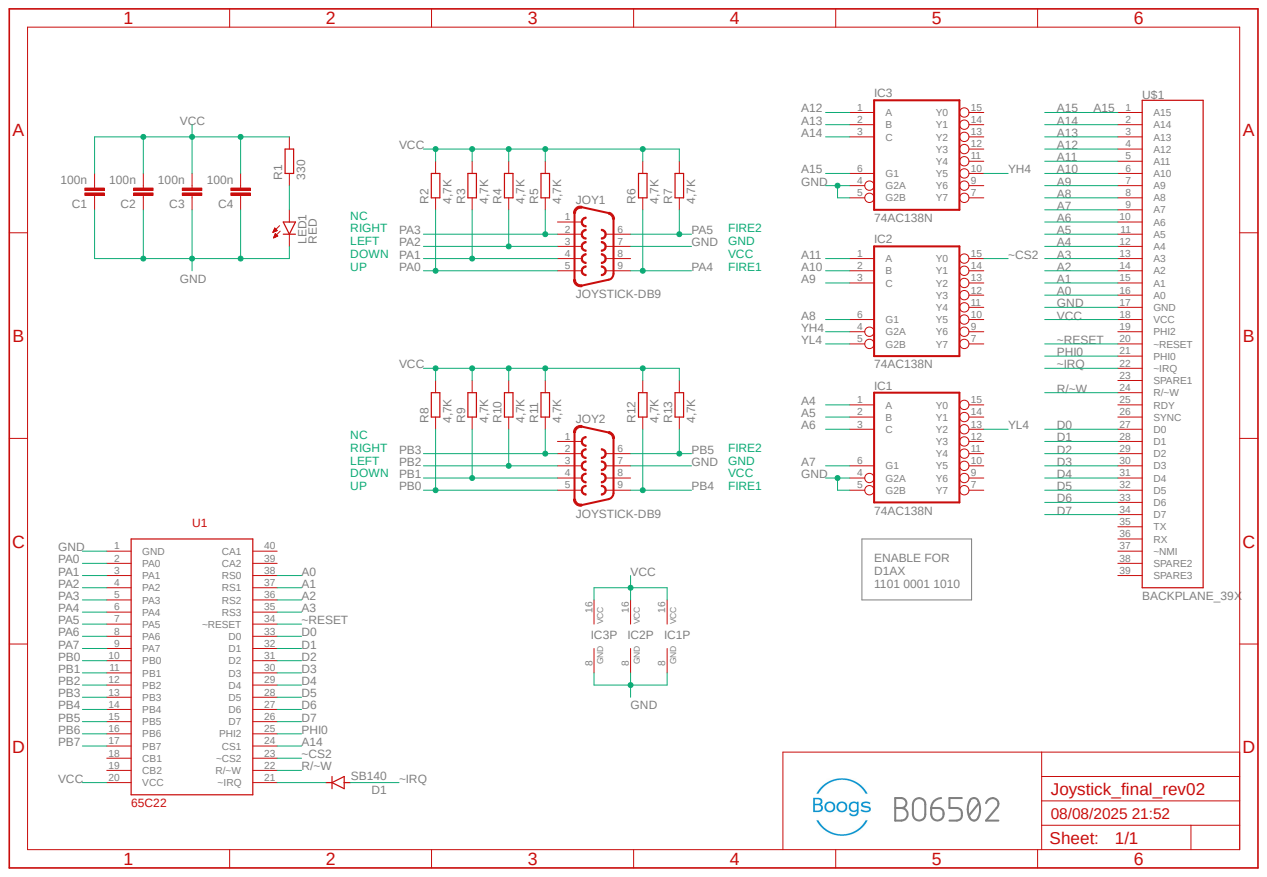
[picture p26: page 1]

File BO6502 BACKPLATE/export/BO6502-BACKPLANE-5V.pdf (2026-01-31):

A

A

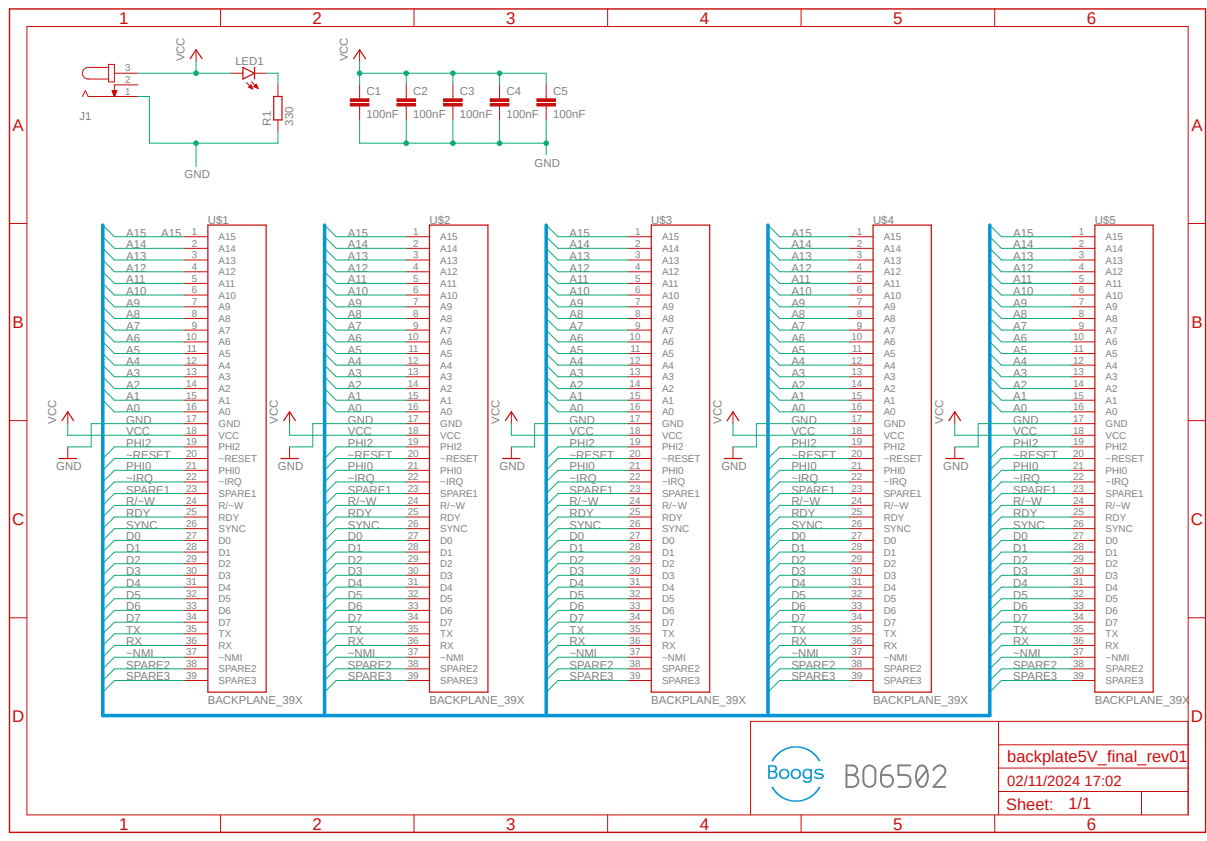
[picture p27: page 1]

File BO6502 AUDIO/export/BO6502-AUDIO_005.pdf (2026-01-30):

100n | 100n 10K
Y7 | 7 Y6 | 9 Y5 | 10 Y4 | 11 Y3 | 12 Y2 | 13 Y1 | 14 Y0 | 15

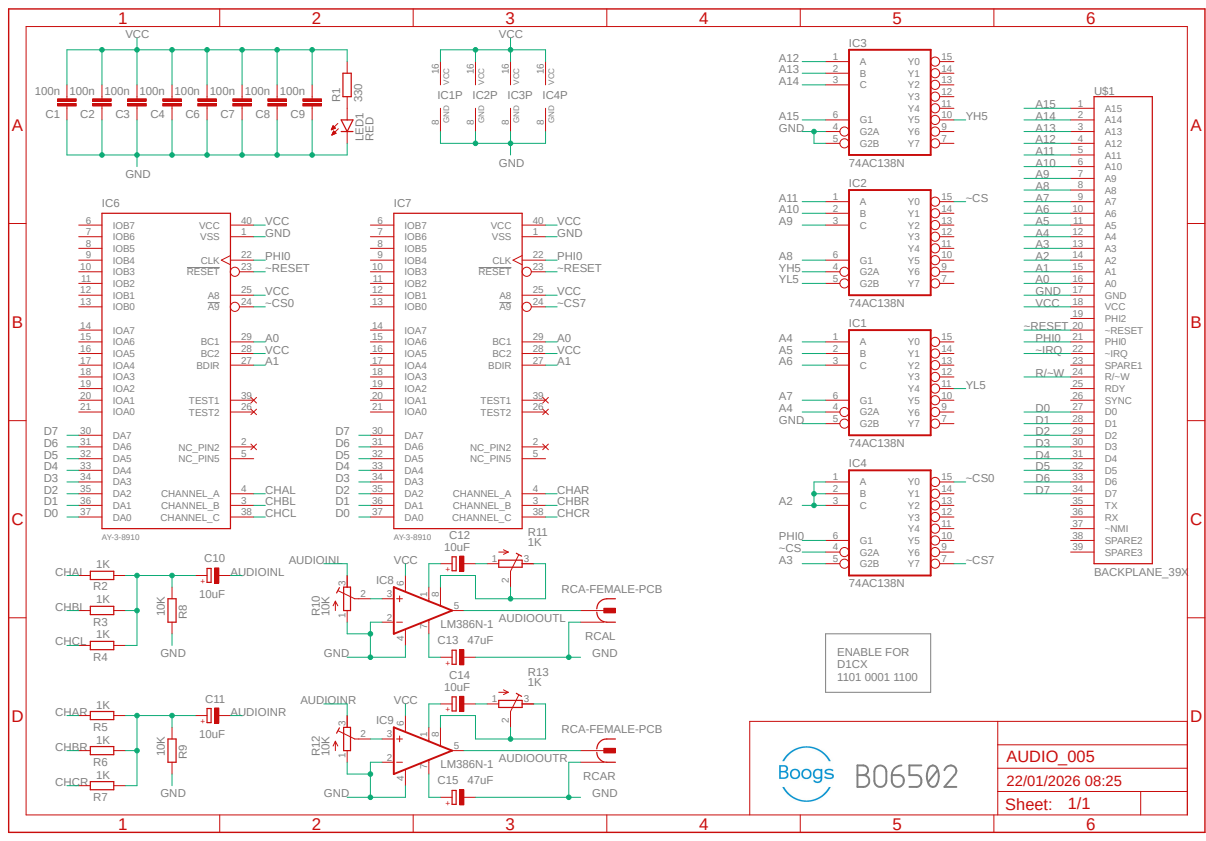
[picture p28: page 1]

VCC | VCC

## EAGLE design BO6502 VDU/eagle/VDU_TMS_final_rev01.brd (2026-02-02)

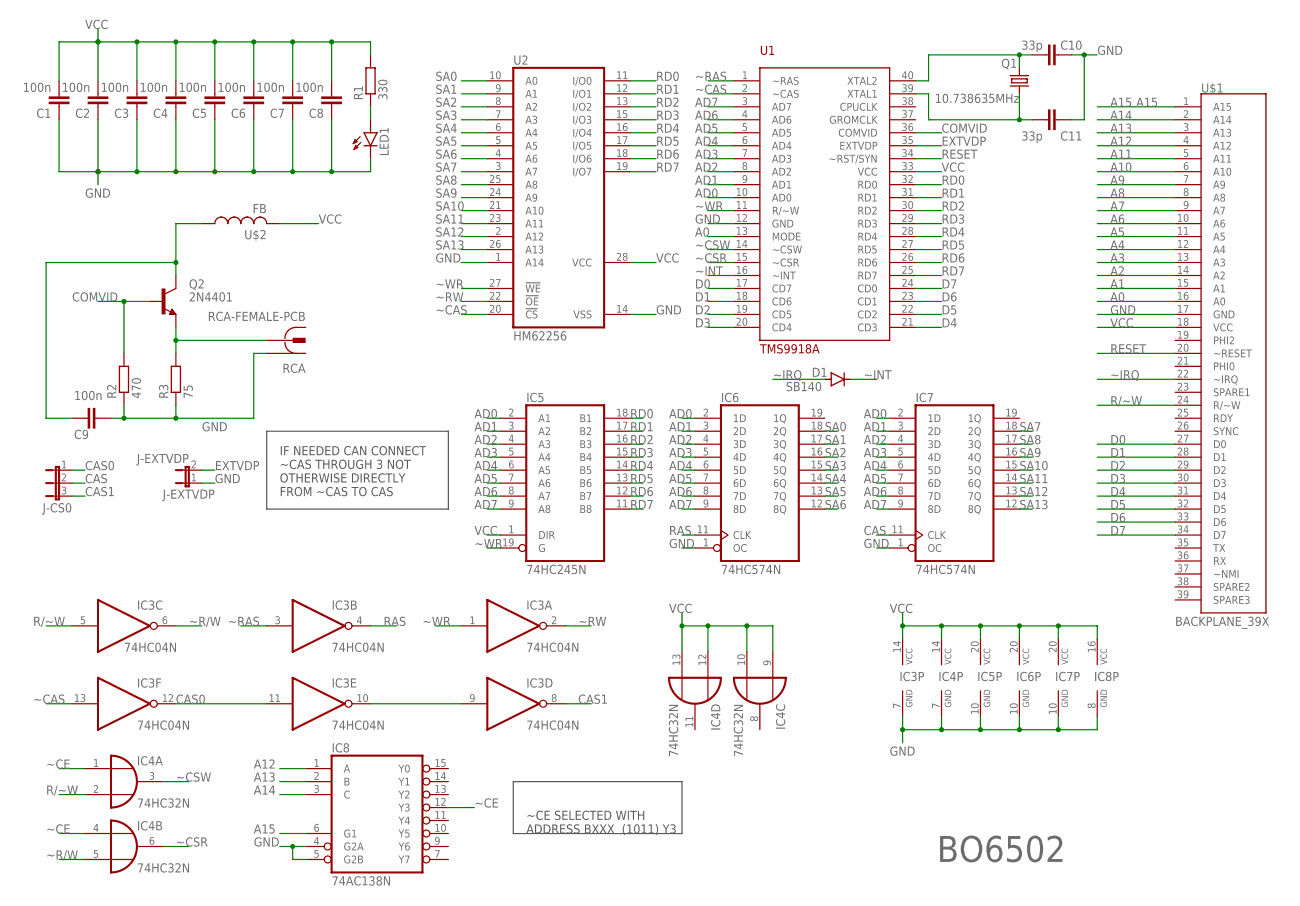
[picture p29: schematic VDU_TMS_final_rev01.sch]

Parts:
C1, C2, C3, C4, C5, C6, C7, C8, C9: 100n; C025-025X050
C10, C11: 33p; C025-025X050
D1: SB140; DO41-10
IC3: 74HC04N; DIL14
IC4: 74HC32N; DIL14
IC5: 74HC245N; DIL20
IC6, IC7: 74HC574N; DIL20
IC8: 74AC138N; DIL16
J-CAS: J-CS0; JP2
J-EXTVDP: J-EXTVDP; JP1
LED1: RED; LED5MM
Q1: 10.738635MHz; HC49/S
Q2: 2N4401; TO92-EBC
R1: 330; 0207/10
R2: 470; 0207/10
R3: 75; 0207/10
RCA: RCA-FEMALE-PCB
U1: TMS9918A; DIL40
U2: HM62256; DIL28-6
U$1: BACKPLANE_39X; BP_39X
U$2: FB

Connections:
A0: U1.13 (MODE), U$1.16 (A0)
A1: U$1.15 (A1)
A2: U$1.14 (A2)
A3: U$1.13 (A3)
A4: U$1.12 (A4)
A5: U$1.11 (A5)
A6: U$1.10 (A6)
A7: U$1.9 (A7)
A8: U$1.8 (A8)
A9: U$1.7 (A9)
A10: U$1.6 (A10)
A11: U$1.5 (A11)
A12: IC8.1 (A), U$1.4 (A12)
A13: IC8.2 (B), U$1.3 (A13)
A14: IC8.3 (C), U$1.2 (A14)
A15: IC8.6 (G1), U$1.1 (A15)
AD0: IC5.2 (A1), IC6.2 (1D), IC7.2 (1D), U1.10 (AD0)
AD1: IC5.3 (A2), IC6.3 (2D), IC7.3 (2D), U1.9 (AD1)
AD2: IC5.4 (A3), IC6.4 (3D), IC7.4 (3D), U1.8 (AD2)
AD3: IC5.5 (A4), IC6.5 (4D), IC7.5 (4D), U1.7 (AD3)
AD4: IC5.6 (A5), IC6.6 (5D), IC7.6 (5D), U1.6 (AD4)
AD5: IC5.7 (A6), IC6.7 (6D), IC7.7 (6D), U1.5 (AD5)
AD6: IC5.8 (A7), IC6.8 (7D), IC7.8 (7D), U1.4 (AD6)
AD7: IC5.9 (A8), IC6.9 (8D), IC7.9 (8D), U1.3 (AD7)
CAS: IC7.11 (CLK), J-CAS.2
CAS0: IC3.11 (I), IC3.12 (O), J-CAS.1
CAS1: IC3.8 (O), J-CAS.3
COMVID: Q2.B, R2.2, U1.36 (COMVID)
D0: U1.17 (CD7), U$1.27 (D0)
D1: U1.18 (CD6), U$1.28 (D1)
D2: U1.19 (CD5), U$1.29 (D2)
D3: U1.20 (CD4), U$1.30 (D3)
D4: U1.21 (CD3), U$1.31 (D4)
D5: U1.22 (CD2), U$1.32 (D5)
D6: U1.23 (CD1), U$1.33 (D6)
D7: U1.24 (CD0), U$1.34 (D7)
EXTVDP: J-EXTVDP.2, U1.35 (EXTVDP)
GND: C1.1, C2.1, C3.1, C4.1, C5.1, C6.1, C7.1, C8.1, C9.1, C10.1, C11.1, IC3.7 (GND), IC4.7 (GND), IC5.10 (GND), IC6.1 (OC), IC6.10 (GND), IC7.1 (OC), IC7.10 (GND), IC8.4 (G2A), IC8.5 (G2B), IC8.8 (GND), J-EXTVDP.1, LED1.K (C), R2.1, R3.1, RCA.1, U1.12 (GND), U2.1 (A14), U2.14 (VSS), U$1.17 (GND)
unnamed: Q2.E, R3.2, RCA.2@1 (2), RCA.2@2 (2)
unnamed: C9.2, Q2.C, U$2.P$1 (1)
unnamed: C10.2, Q1.2, U1.40 (XTAL2)
unnamed: LED1.A, R1.1
unnamed: C11.2, Q1.1, U1.39 (XTAL1)
unnamed: IC3.9 (I), IC3.10 (O)
R/~W: IC3.5 (I), IC4.2 (I1), U$1.24 (R/~W)
RAS: IC3.4 (O), IC6.11 (CLK)
RD0: IC5.18 (B1), U1.32 (RD0), U2.11 (I/O0)
RD1: IC5.17 (B2), U1.31 (RD1), U2.12 (I/O1)
RD2: IC5.16 (B3), U1.30 (RD2), U2.13 (I/O2)
RD3: IC5.15 (B4), U1.29 (RD3), U2.15 (I/O3)
RD4: IC5.14 (B5), U1.28 (RD4), U2.16 (I/O4)
RD5: IC5.13 (B6), U1.27 (RD5), U2.17 (I/O5)
RD6: IC5.12 (B7), U1.26 (RD6), U2.18 (I/O6)
RD7: IC5.11 (B8), U1.25 (RD7), U2.19 (I/O7)
RESET: U1.34 (~RST/SYN), U$1.20 (~RESET)
SA0: IC6.18 (2Q), U2.10 (A0)
SA1: IC6.17 (3Q), U2.9 (A1)
SA2: IC6.16 (4Q), U2.8 (A2)
SA3: IC6.15 (5Q), U2.7 (A3)
SA4: IC6.14 (6Q), U2.6 (A4)
SA5: IC6.13 (7Q), U2.5 (A5)
SA6: IC6.12 (8Q), U2.4 (A6)
SA7: IC7.18 (2Q), U2.3 (A7)
SA8: IC7.17 (3Q), U2.25 (A8)
SA9: IC7.16 (4Q), U2.24 (A9)
SA10: IC7.15 (5Q), U2.21 (A10)
SA11: IC7.14 (6Q), U2.23 (A11)
SA12: IC7.13 (7Q), U2.2 (A12)
SA13: IC7.12 (8Q), U2.26 (A13)
VCC: C1.2, C2.2, C3.2, C4.2, C5.2, C6.2, C7.2, C8.2, IC3.14 (VCC), IC4.9 (I0), IC4.10 (I1), IC4.12 (I0), IC4.13 (I1), IC4.14 (VCC), IC5.1 (DIR), IC5.20 (VCC), IC6.20 (VCC), IC7.20 (VCC), IC8.16 (VCC), R1.2, U1.33 (VCC), U2.28 (VCC), U$1.18 (VCC), U$2.P$2 (2)
~CAS: IC3.13 (I), U1.2 (~CAS), U2.20 (!CS)
~CE: IC4.1 (I0), IC4.4 (I0), IC8.12 (Y3)
~CSR: IC4.6 (O), U1.15 (~CSR)
~CSW: IC4.3 (O), U1.14 (~CSW)
~INT: D1.C, U1.16 (~INT)
~IRQ: D1.A, U$1.22 (~IRQ)
~R/W: IC3.6 (O), IC4.5 (I1)
~RAS: IC3.3 (I), U1.1 (~RAS)
~RW: IC3.2 (O), U2.22 (!OE)
~WR: IC3.1 (I), IC5.19 (G), U1.11 (R/~W), U2.27 (!WE)

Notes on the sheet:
BO6502
IF NEEDED CAN CONNECT ~CAS THROUGH 3 NOT OTHERWISE DIRECTLY FROM ~CAS TO CAS
~CE SELECTED WITH ADDRESS BXXX (1011) Y3

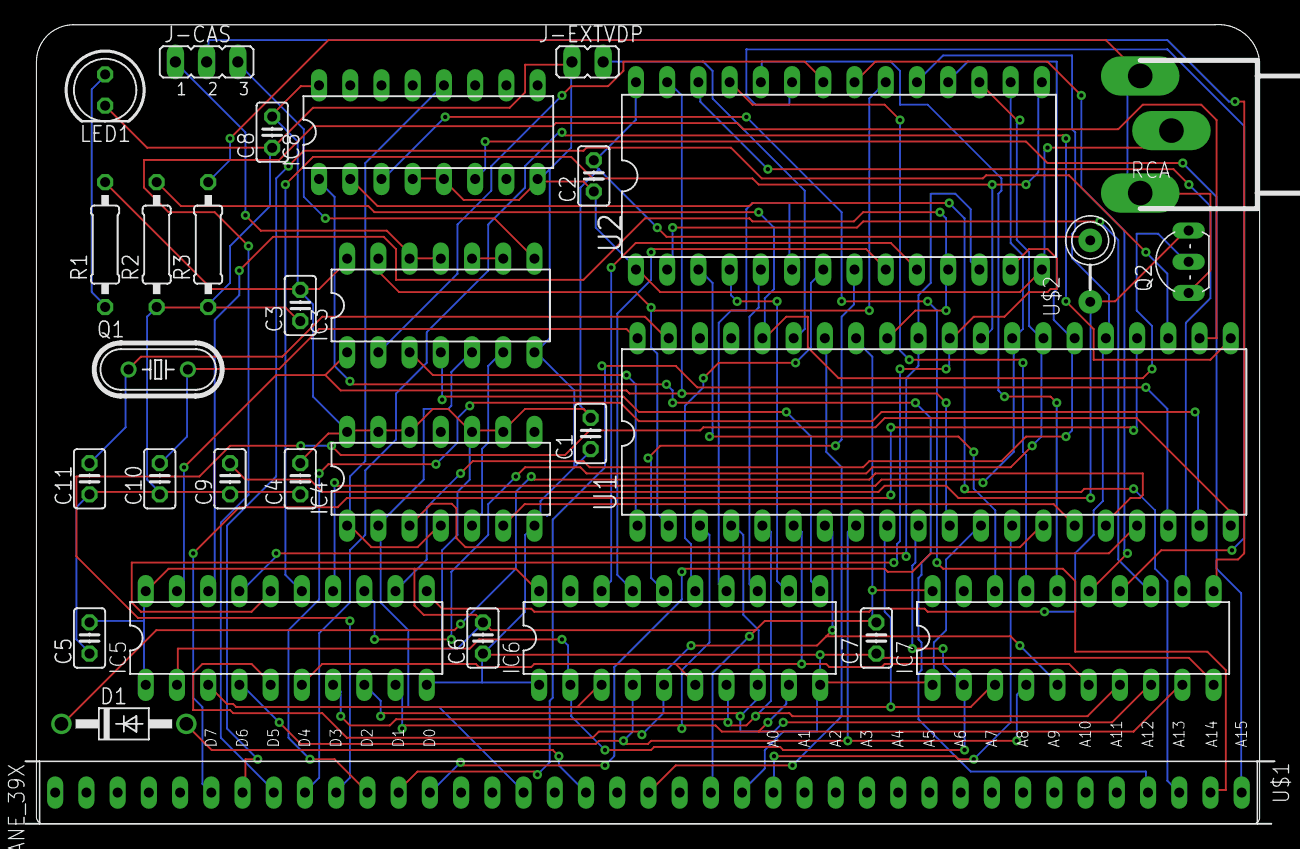
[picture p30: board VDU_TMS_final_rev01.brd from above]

Board: 2 copper layers, 101.6 x 65.0 mm, 31 parts (0 on the bottom side), 69 nets.

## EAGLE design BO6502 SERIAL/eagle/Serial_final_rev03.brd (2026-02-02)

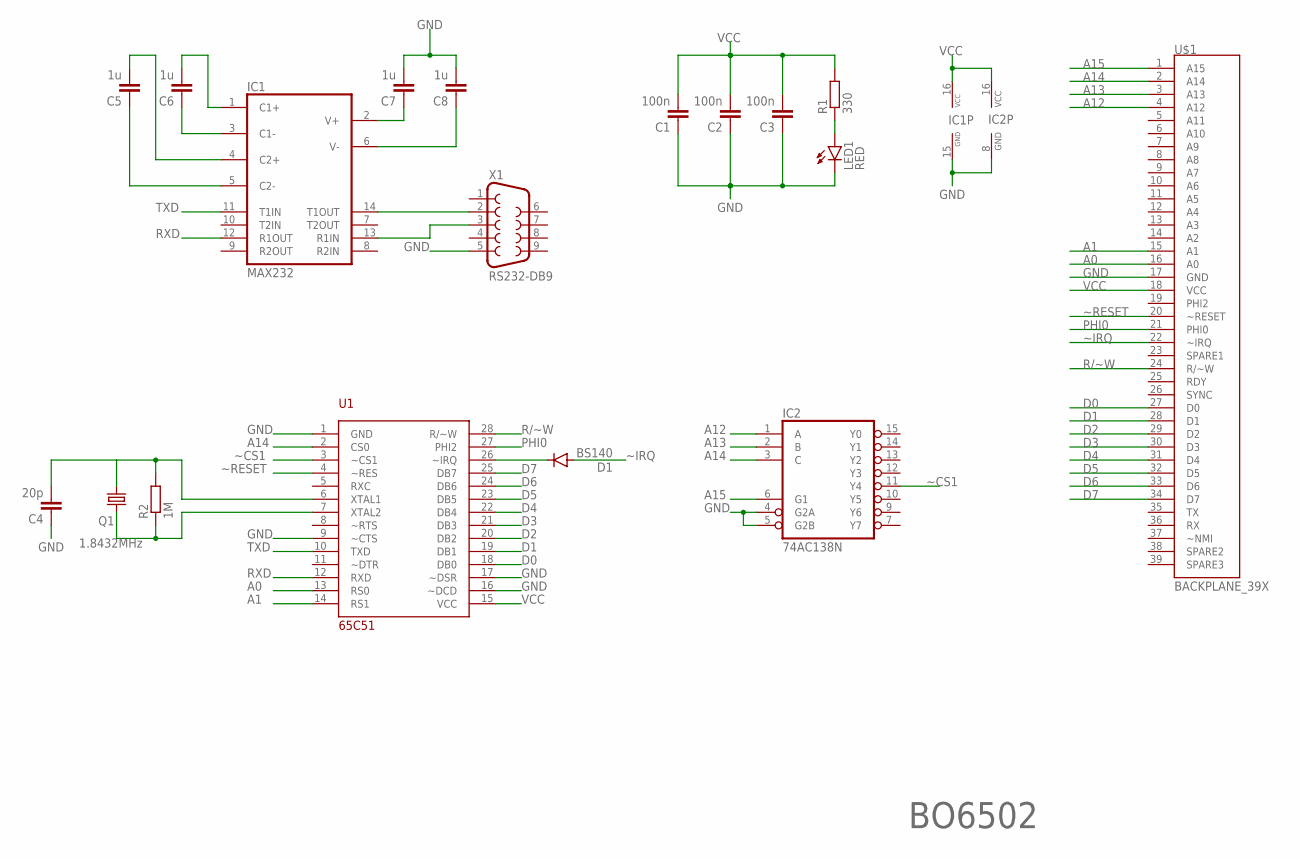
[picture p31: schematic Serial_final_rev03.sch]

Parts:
C1, C2, C3: 100n; C025-025X050
C4: 20p; C025-025X050
C5, C6, C7, C8: 1u; C050-025X075
D1: BS140; DO41-10
IC1: MAX232; DIL16
IC2: 74AC138N; DIL16
LED1: RED; LED5MM
Q1: 1.8432MHz; HC49/S
R1: 330; 0207/10
R2: 1M; 0207/10
U1: 65C51; DIL28
U$1: BACKPLANE_39X; BP_39X
X1: RS232-DB9; F09HP

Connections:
A0: U1.13 (RS0), U$1.16 (A0)
A1: U1.14 (RS1), U$1.15 (A1)
A12: IC2.1 (A), U$1.4 (A12)
A13: IC2.2 (B), U$1.3 (A13)
A14: IC2.3 (C), U1.2 (CS0), U$1.2 (A14)
A15: IC2.6 (G1), U$1.1 (A15)
D0: U1.18 (DB0), U$1.27 (D0)
D1: U1.19 (DB1), U$1.28 (D1)
D2: U1.20 (DB2), U$1.29 (D2)
D3: U1.21 (DB3), U$1.30 (D3)
D4: U1.22 (DB4), U$1.31 (D4)
D5: U1.23 (DB5), U$1.32 (D5)
D6: U1.24 (DB6), U$1.33 (D6)
D7: U1.25 (DB7), U$1.34 (D7)
GND: C1.1, C2.1, C3.1, C4.1, C7.2, C8.2, IC1.15 (GND), IC2.4 (G2A), IC2.5 (G2B), IC2.8 (GND), LED1.K (C), U1.1 (GND), U1.9 (~CTS), U1.16 (~DCD), U1.17 (~DSR), U$1.17 (GND), X1.5
unnamed: C6.2, IC1.1 (C1+)
unnamed: D1.C, U1.26 (~IRQ)
unnamed: C6.1, IC1.3 (C1-)
unnamed: C5.2, IC1.4 (C2+)
unnamed: C5.1, IC1.5 (C2-)
unnamed: LED1.A, R1.1
unnamed: IC1.14 (T1OUT), X1.2
unnamed: IC1.13 (R1IN), X1.3
unnamed: C7.1, IC1.2 (V+)
unnamed: C8.1, IC1.6 (V-)
unnamed: C4.2, Q1.2, R2.2, U1.6 (XTAL1)
unnamed: Q1.1, R2.1, U1.7 (XTAL2)
PHI0: U1.27 (PHI2), U$1.21 (PHI0)
R/~W: U1.28 (R/~W), U$1.24 (R/~W)
RXD: IC1.12 (R1OUT), U1.12 (RXD)
TXD: IC1.11 (T1IN), U1.10 (TXD)
VCC: C1.2, C2.2, C3.2, IC1.16 (VCC), IC2.16 (VCC), R1.2, U1.15 (VCC), U$1.18 (VCC)
~CS1: IC2.11 (Y4), U1.3 (~CS1)
~IRQ: D1.A, U$1.22 (~IRQ)
~RESET: U1.4 (~RES), U$1.20 (~RESET)

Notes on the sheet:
BO6502

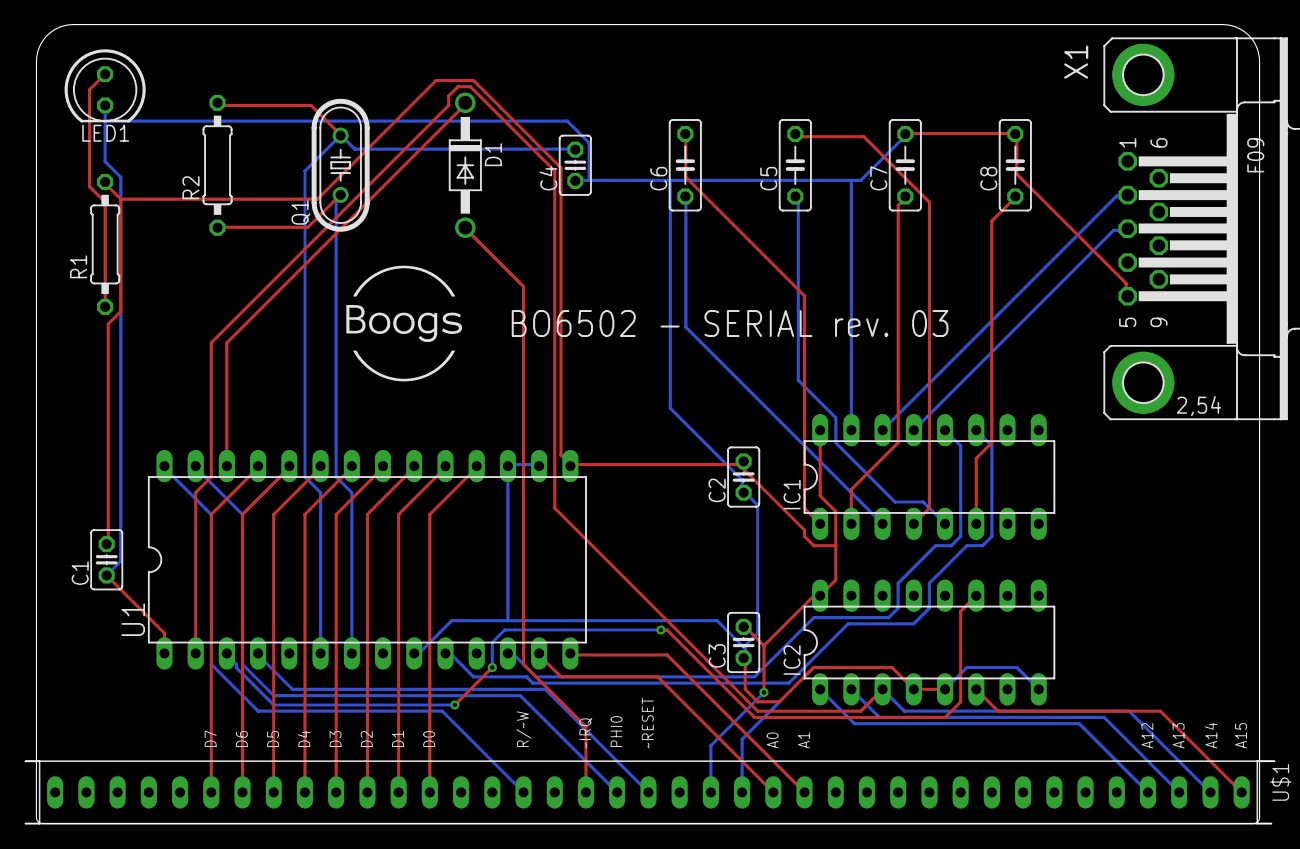
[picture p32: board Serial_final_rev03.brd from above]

Board: 2 copper layers, 101.6 x 65.0 mm, 18 parts (0 on the bottom side), 35 nets.

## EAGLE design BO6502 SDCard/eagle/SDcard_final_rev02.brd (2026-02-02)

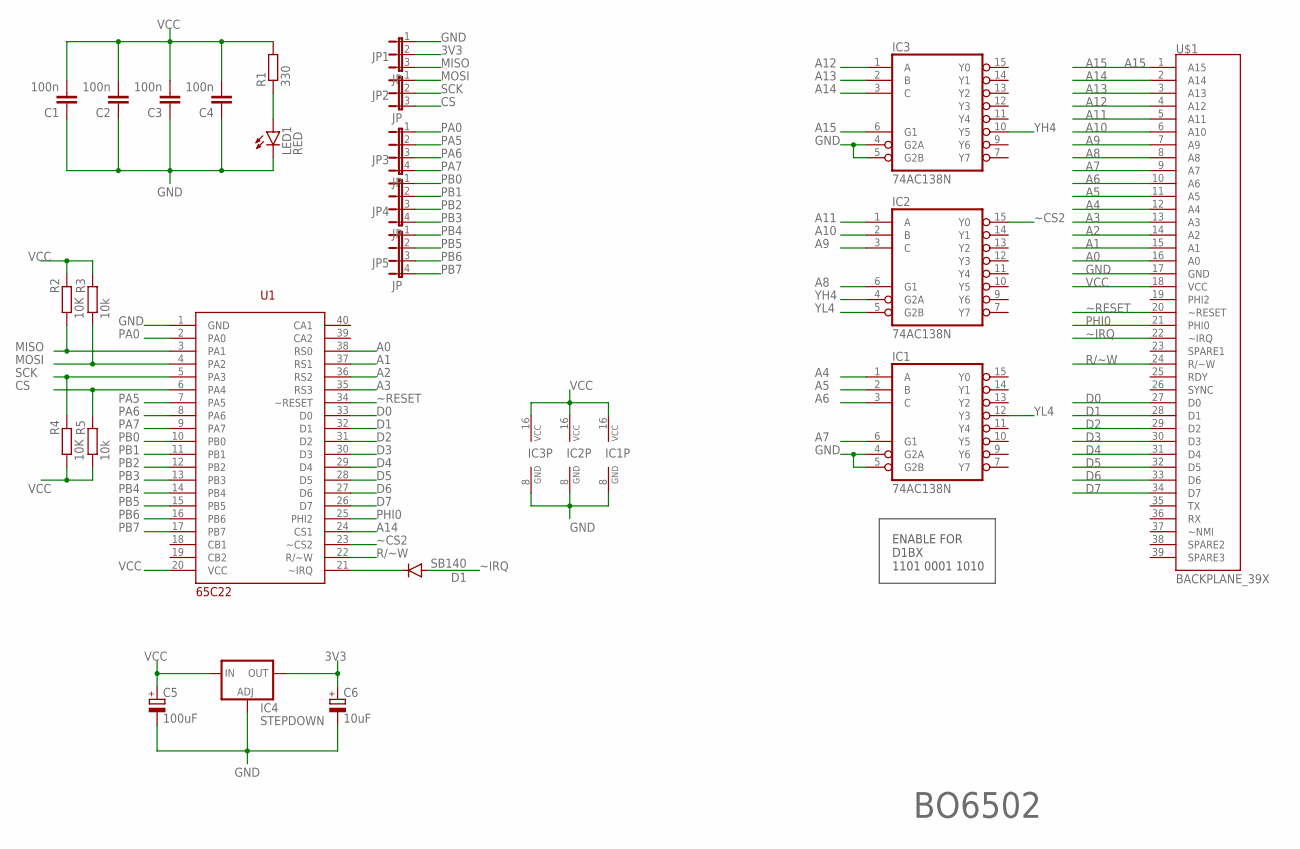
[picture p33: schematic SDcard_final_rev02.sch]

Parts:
C1, C2, C3, C4: 100n; C025-025X050
C5: 100uF; B45181A
C6: 10uF; B45181A
D1: SB140; DO41-10
IC1, IC2, IC3: 74AC138N; DIL16
IC4: STEPDOWN; 317TS
JP1, JP2: JP; JP2
JP3, JP4, JP5: JP; JP4
LED1: RED; LED5MM
R1: 330; 0207/10
R2, R4: 10K; 0207/10
R3, R5: 10k; 0207/10
U1: 65C22; DIL40
U$1: BACKPLANE_39X; BP_39X

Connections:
3V3: C6.+, IC4.2 (OUT), JP1.2
A0: U1.38 (RS0), U$1.16 (A0)
A1: U1.37 (RS1), U$1.15 (A1)
A2: U1.36 (RS2), U$1.14 (A2)
A3: U1.35 (RS3), U$1.13 (A3)
A4: IC1.1 (A), U$1.12 (A4)
A5: IC1.2 (B), U$1.11 (A5)
A6: IC1.3 (C), U$1.10 (A6)
A7: IC1.6 (G1), U$1.9 (A7)
A8: IC2.6 (G1), U$1.8 (A8)
A9: IC2.3 (C), U$1.7 (A9)
A10: IC2.2 (B), U$1.6 (A10)
A11: IC2.1 (A), U$1.5 (A11)
A12: IC3.1 (A), U$1.4 (A12)
A13: IC3.2 (B), U$1.3 (A13)
A14: IC3.3 (C), U1.24 (CS1), U$1.2 (A14)
A15: IC3.6 (G1), U$1.1 (A15)
CS: JP2.3, R5.2, U1.6 (PA4)
D0: U1.33 (D0), U$1.27 (D0)
D1: U1.32 (D1), U$1.28 (D1)
D2: U1.31 (D2), U$1.29 (D2)
D3: U1.30 (D3), U$1.30 (D3)
D4: U1.29 (D4), U$1.31 (D4)
D5: U1.28 (D5), U$1.32 (D5)
D6: U1.27 (D6), U$1.33 (D6)
D7: U1.26 (D7), U$1.34 (D7)
GND: C1.1, C2.1, C3.1, C4.1, C5.-, C6.-, IC1.4 (G2A), IC1.5 (G2B), IC1.8 (GND), IC2.8 (GND), IC3.4 (G2A), IC3.5 (G2B), IC3.8 (GND), IC4.1 (ADJ), JP1.1, LED1.K (C), U1.1 (GND), U$1.17 (GND)
MISO: JP1.3, R2.1, U1.3 (PA1)
MOSI: JP2.1, R3.1, U1.4 (PA2)
unnamed: D1.C, U1.21 (~IRQ)
unnamed: LED1.A, R1.1
PA0: JP3.1, U1.2 (PA0)
PA5: JP3.2, U1.7 (PA5)
PA6: JP3.3, U1.8 (PA6)
PA7: JP3.4, U1.9 (PA7)
PB0: JP4.1, U1.10 (PB0)
PB1: JP4.2, U1.11 (PB1)
PB2: JP4.3, U1.12 (PB2)
PB3: JP4.4, U1.13 (PB3)
PB4: JP5.1, U1.14 (PB4)
PB5: JP5.2, U1.15 (PB5)
PB6: JP5.3, U1.16 (PB6)
PB7: JP5.4, U1.17 (PB7)
PHI0: U1.25 (PHI2), U$1.21 (PHI0)
R/~W: U1.22 (R/~W), U$1.24 (R/~W)
SCK: JP2.2, R4.2, U1.5 (PA3)
VCC: C1.2, C2.2, C3.2, C4.2, C5.+, IC1.16 (VCC), IC2.16 (VCC), IC3.16 (VCC), IC4.3 (IN), R1.2, R2.2, R3.2, R4.1, R5.1, U1.20 (VCC), U$1.18 (VCC)
YH4: IC2.4 (G2A), IC3.10 (Y5)
YL4: IC1.12 (Y3), IC2.5 (G2B)
~CS2: IC2.15 (Y0), U1.23 (~CS2)
~IRQ: D1.A, U$1.22 (~IRQ)
~RESET: U1.34 (~RESET), U$1.20 (~RESET)

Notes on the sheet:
BO6502
ENABLE FOR D1BX 1101 0001 1010

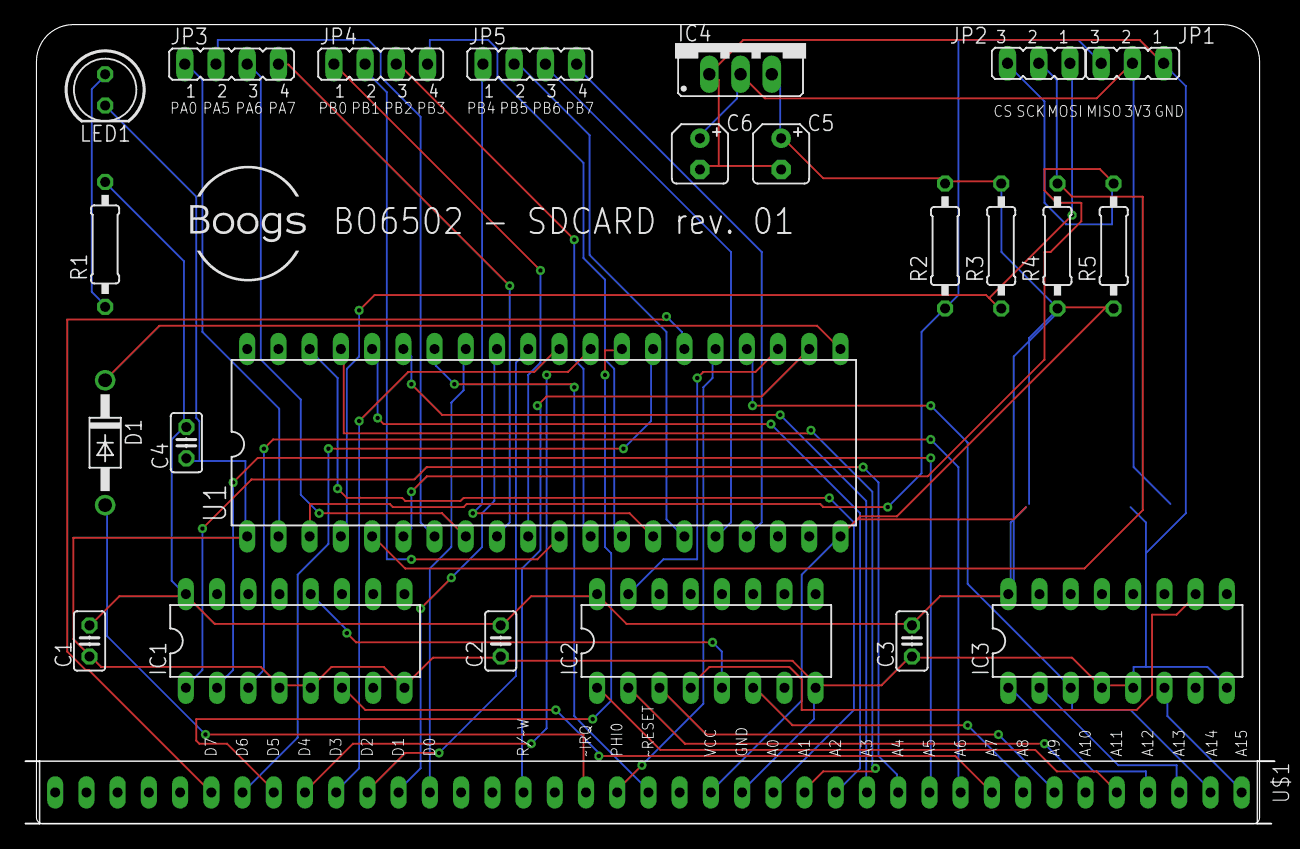
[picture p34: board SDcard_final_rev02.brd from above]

Board: 2 copper layers, 101.6 x 65.0 mm, 24 parts (0 on the bottom side), 52 nets.

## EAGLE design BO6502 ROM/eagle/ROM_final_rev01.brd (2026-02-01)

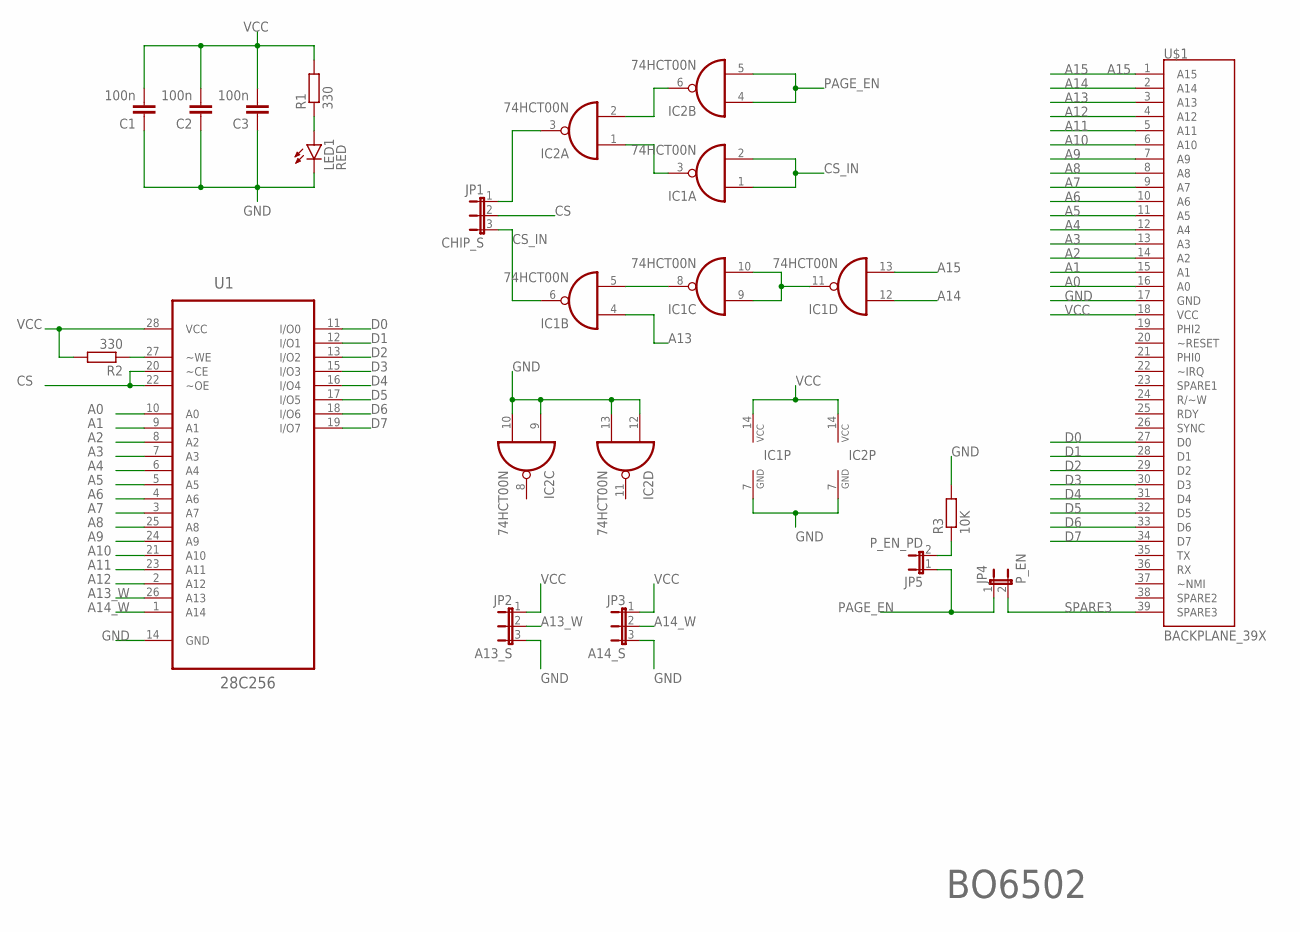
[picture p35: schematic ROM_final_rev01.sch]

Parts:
C1, C2, C3: 100n; C025-025X050
IC1, IC2: 74HCT00N; DIL14
JP1: CHIP_S; JP2
JP2: A13_S; JP2
JP3: A14_S; JP2
JP4: P_EN; JP1
JP5: P_EN_PD; JP1
LED1: RED; LED5MM
R1, R2: 330; 0207/10
R3: 10K; 0207/10
U1: 28C256; DIP254P1524X482-28
U$1: BACKPLANE_39X; BP_39X

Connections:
A0: U1.10 (A0), U$1.16 (A0)
A1: U1.9 (A1), U$1.15 (A1)
A2: U1.8 (A2), U$1.14 (A2)
A3: U1.7 (A3), U$1.13 (A3)
A4: U1.6 (A4), U$1.12 (A4)
A5: U1.5 (A5), U$1.11 (A5)
A6: U1.4 (A6), U$1.10 (A6)
A7: U1.3 (A7), U$1.9 (A7)
A8: U1.25 (A8), U$1.8 (A8)
A9: U1.24 (A9), U$1.7 (A9)
A10: U1.21 (A10), U$1.6 (A10)
A11: U1.23 (A11), U$1.5 (A11)
A12: U1.2 (A12), U$1.4 (A12)
A13: IC1.4 (I0), U$1.3 (A13)
A13_W: JP2.2, U1.26 (A13)
A14: IC1.12 (I0), U$1.2 (A14)
A14_W: JP3.2, U1.1 (A14)
A15: IC1.13 (I1), U$1.1 (A15)
CS: JP1.2, U1.20 (~CE), U1.22 (~OE)
CS_IN: IC1.1 (I0), IC1.2 (I1), IC1.6 (O), JP1.3
D0: U1.11 (I/O0), U$1.27 (D0)
D1: U1.12 (I/O1), U$1.28 (D1)
D2: U1.13 (I/O2), U$1.29 (D2)
D3: U1.15 (I/O3), U$1.30 (D3)
D4: U1.16 (I/O4), U$1.31 (D4)
D5: U1.17 (I/O5), U$1.32 (D5)
D6: U1.18 (I/O6), U$1.33 (D6)
D7: U1.19 (I/O7), U$1.34 (D7)
GND: C1.1, C2.1, C3.1, IC1.7 (GND), IC2.7 (GND), IC2.9 (I0), IC2.10 (I1), IC2.12 (I0), IC2.13 (I1), JP2.3, JP3.3, LED1.K (C), R3.2, U1.14 (GND), U$1.17 (GND)
unnamed: R2.1, U1.27 (~WE)
unnamed: IC2.2 (I1), IC2.6 (O)
unnamed: IC1.3 (O), IC2.1 (I0)
unnamed: IC2.3 (O), JP1.1
unnamed: IC1.5 (I1), IC1.8 (O)
unnamed: LED1.A, R1.1
unnamed: IC1.9 (I0), IC1.10 (I1), IC1.11 (O)
unnamed: JP5.2, R3.1
PAGE_EN: IC2.4 (I0), IC2.5 (I1), JP4.1, JP5.1
SPARE3: JP4.2, U$1.39 (SPARE3)
VCC: C1.2, C2.2, C3.2, IC1.14 (VCC), IC2.14 (VCC), JP2.1, JP3.1, R1.2, R2.2, U1.28 (VCC), U$1.18 (VCC)

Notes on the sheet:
BO6502

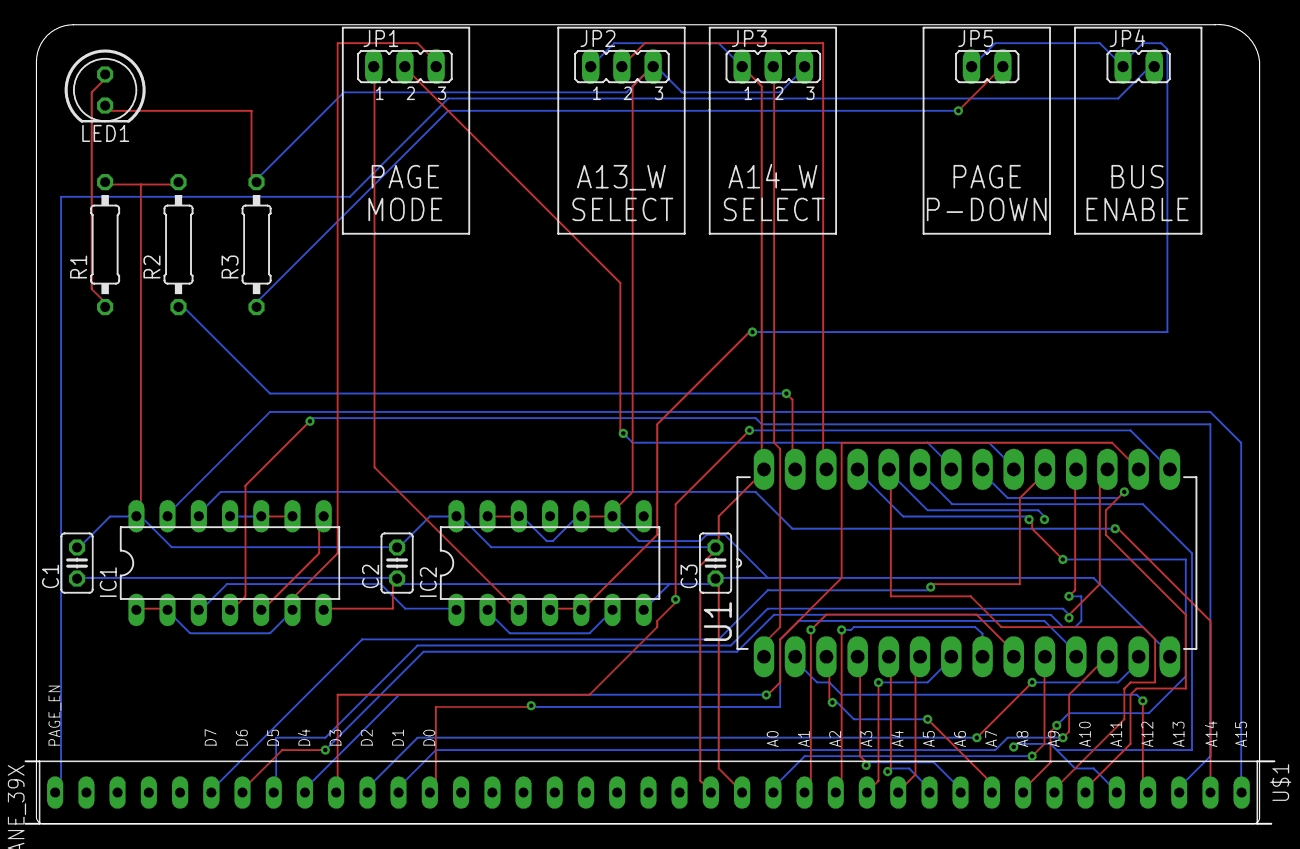
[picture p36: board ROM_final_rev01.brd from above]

Board: 2 copper layers, 101.6 x 65.0 mm, 16 parts (0 on the bottom side), 40 nets.

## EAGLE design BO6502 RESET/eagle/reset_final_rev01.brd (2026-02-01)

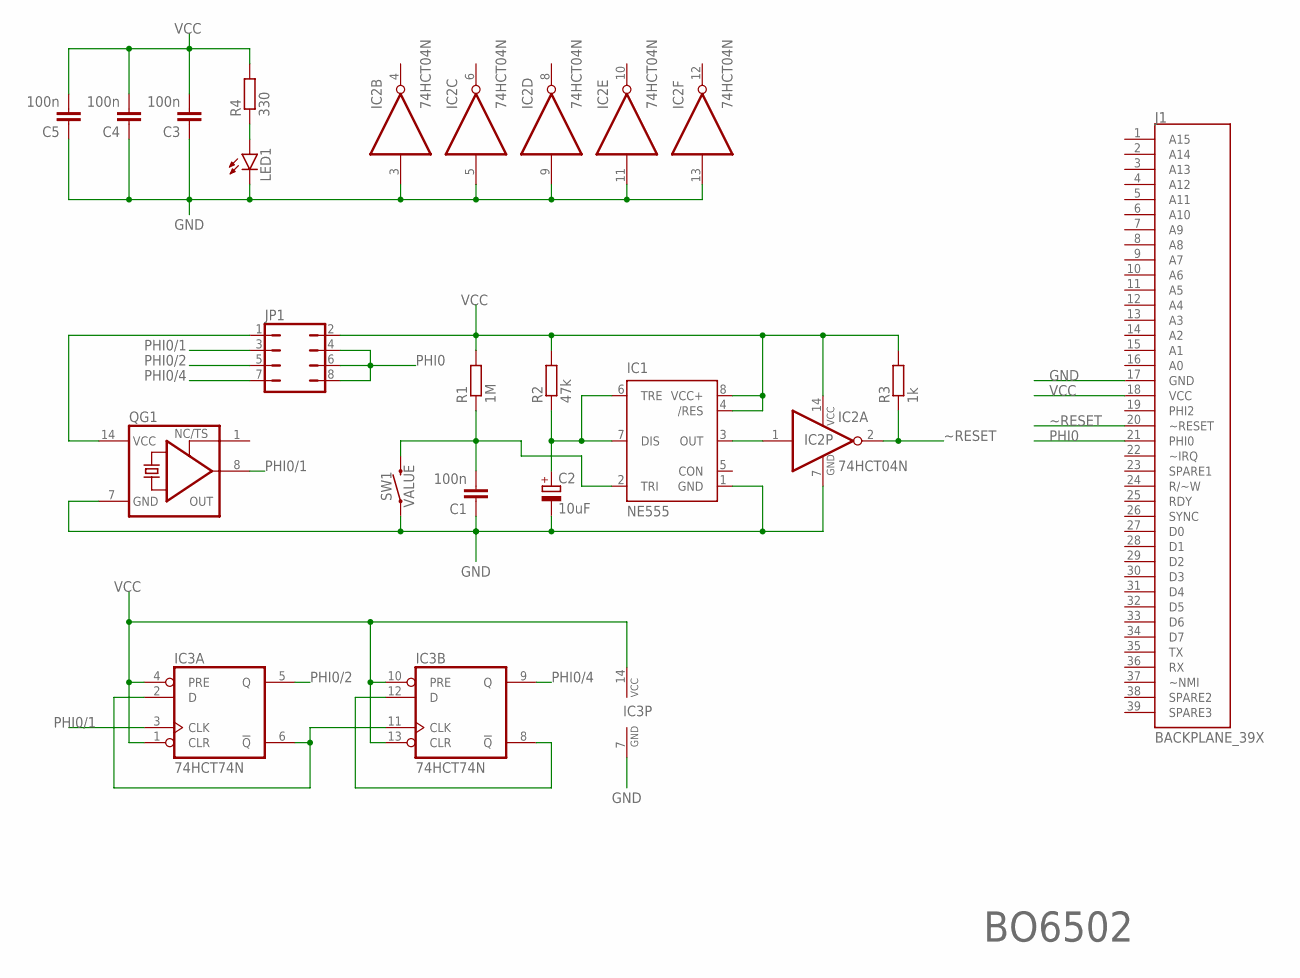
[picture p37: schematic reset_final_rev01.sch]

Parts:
C1, C3, C4, C5: 100n; C025-025X050
C2: 10uF; B45181A
IC1: NE555; DIL-08
IC2: 74HCT04N; DIL14
IC3: 74HCT74N; DIL14
J1: BACKPLANE_39X; BP_39X
JP1: JP4Q
LED1: LED5MM
QG1: XO-14; DIL14S
R1: 1M; 0207/10
R2: 47k; 0207/10
R3: 1k; 0207/10
R4: 330; 0207/10
SW1: MOMENTARY-SWITCH-SPST-PTH-6.0MM-KIT; TACTILE_SWITCH_PTH_6.0MM_KIT

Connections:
GND: C1.1, C2.-, C3.1, C4.1, C5.1, IC1.1 (GND), IC2.3 (I), IC2.5 (I), IC2.7 (GND), IC2.9 (I), IC2.11 (I), IC2.13 (I), IC3.7 (GND), J1.17 (GND), LED1.K (C), QG1.7 (GND), SW1.1
unnamed: JP1.1, QG1.14 (VCC)
unnamed: IC1.3 (OUT), IC2.1 (I)
unnamed: C2.+, IC1.6 (TRE), IC1.7 (DIS), R2.1
unnamed: C1.2, IC1.2 (TRI), R1.1, SW1.3 (2)
unnamed: LED1.A, R4.1
unnamed: IC3.2 (D), IC3.6 (!Q), IC3.11 (CLK)
unnamed: IC3.8 (!Q), IC3.12 (D)
PHI0: J1.21 (PHI0), JP1.4, JP1.6, JP1.8
PHI0/1: IC3.3 (CLK), JP1.3, QG1.8 (OUT)
PHI0/2: IC3.5 (Q), JP1.5
PHI0/4: IC3.9 (Q), JP1.7
VCC: C3.2, C4.2, C5.2, IC1.4 (/RES), IC1.8 (VCC+), IC2.14 (VCC), IC3.1 (CLR), IC3.4 (PRE), IC3.10 (PRE), IC3.13 (CLR), IC3.14 (VCC), J1.18 (VCC), JP1.2, R1.2, R2.2, R3.2, R4.2
~RESET: IC2.2 (O), J1.20 (~RESET), R3.1

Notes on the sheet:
BO6502

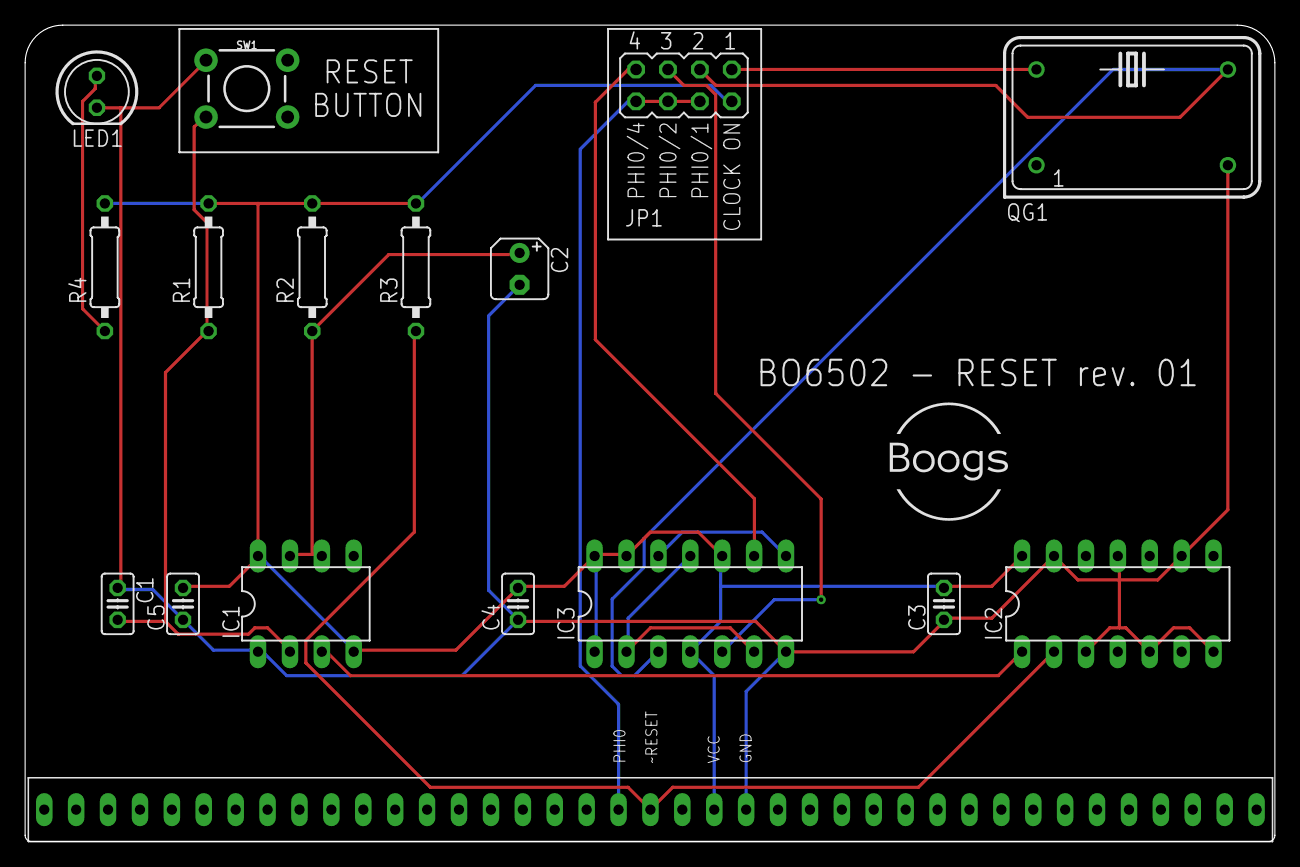
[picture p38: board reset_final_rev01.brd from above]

Board: 2 copper layers, 99.5 x 65.0 mm, 17 parts (0 on the bottom side), 14 nets.

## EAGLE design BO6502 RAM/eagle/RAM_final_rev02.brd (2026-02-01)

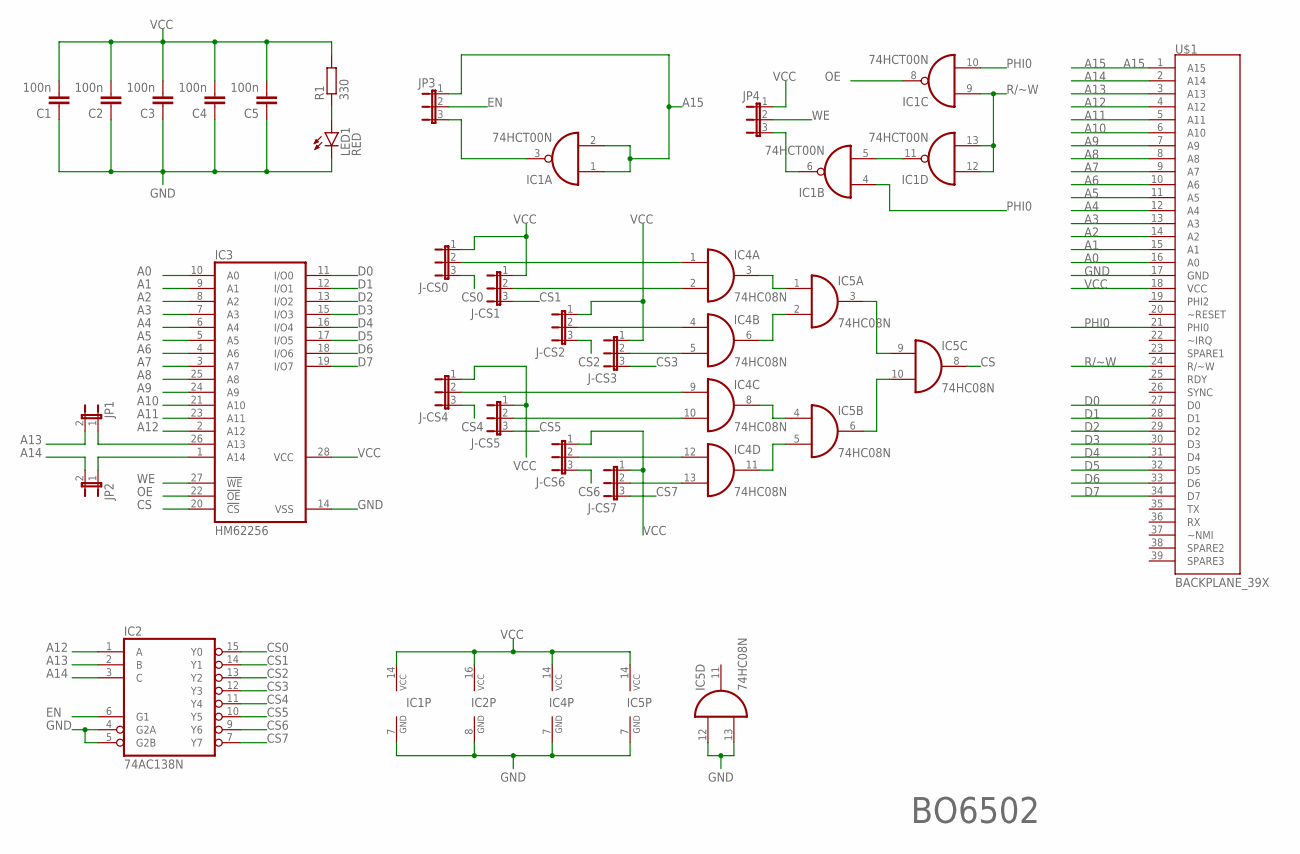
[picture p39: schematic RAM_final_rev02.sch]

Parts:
C1, C2, C3, C4, C5: 100n; C025-025X050
IC1: 74HCT00N; DIL14
IC2: 74AC138N; DIL16
IC3: HM62256; DIL28-6
IC4, IC5: 74HC08N; DIL14
J-CS0: J-CS0; JP2
J-CS1: J-CS1; JP2
J-CS2: J-CS2; JP2
J-CS3: J-CS3; JP2
J-CS4: J-CS4; JP2
J-CS5: J-CS5; JP2
J-CS6: J-CS6; JP2
J-CS7: J-CS7; JP2
JP1: JP1
JP2: JP2; JP1
JP3: JP3; JP2
JP4: JP4; JP2
LED1: RED; LED5MM
R1: 330; 0207/10
U$1: BACKPLANE_39X; BP_39X

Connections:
A0: IC3.10 (A0), U$1.16 (A0)
A1: IC3.9 (A1), U$1.15 (A1)
A2: IC3.8 (A2), U$1.14 (A2)
A3: IC3.7 (A3), U$1.13 (A3)
A4: IC3.6 (A4), U$1.12 (A4)
A5: IC3.5 (A5), U$1.11 (A5)
A6: IC3.4 (A6), U$1.10 (A6)
A7: IC3.3 (A7), U$1.9 (A7)
A8: IC3.25 (A8), U$1.8 (A8)
A9: IC3.24 (A9), U$1.7 (A9)
A10: IC3.21 (A10), U$1.6 (A10)
A11: IC3.23 (A11), U$1.5 (A11)
A12: IC2.1 (A), IC3.2 (A12), U$1.4 (A12)
A13: IC2.2 (B), JP1.2, U$1.3 (A13)
A14: IC2.3 (C), JP2.2, U$1.2 (A14)
A15: IC1.1 (I0), IC1.2 (I1), JP3.1, U$1.1 (A15)
CS: IC3.20 (!CS), IC5.8 (O)
CS0: IC2.15 (Y0), J-CS0.3
CS1: IC2.14 (Y1), J-CS1.3
CS2: IC2.13 (Y2), J-CS2.3
CS3: IC2.12 (Y3), J-CS3.3
CS4: IC2.11 (Y4), J-CS4.3
CS5: IC2.10 (Y5), J-CS5.3
CS6: IC2.9 (Y6), J-CS6.3
CS7: IC2.7 (Y7), J-CS7.3
D0: IC3.11 (I/O0), U$1.27 (D0)
D1: IC3.12 (I/O1), U$1.28 (D1)
D2: IC3.13 (I/O2), U$1.29 (D2)
D3: IC3.15 (I/O3), U$1.30 (D3)
D4: IC3.16 (I/O4), U$1.31 (D4)
D5: IC3.17 (I/O5), U$1.32 (D5)
D6: IC3.18 (I/O6), U$1.33 (D6)
D7: IC3.19 (I/O7), U$1.34 (D7)
EN: IC2.6 (G1), JP3.2
GND: C1.1, C2.1, C3.1, C4.1, C5.1, IC1.7 (GND), IC2.4 (G2A), IC2.5 (G2B), IC2.8 (GND), IC3.14 (VSS), IC4.7 (GND), IC5.7 (GND), IC5.12 (I0), IC5.13 (I1), LED1.K (C), U$1.17 (GND)
unnamed: IC3.26 (A13), JP1.1
unnamed: IC1.5 (I1), IC1.11 (O)
unnamed: IC1.3 (O), JP3.3
unnamed: IC1.6 (O), JP4.3
unnamed: IC4.3 (O), IC5.1 (I0)
unnamed: LED1.A, R1.1
unnamed: IC4.6 (O), IC5.2 (I1)
unnamed: IC4.8 (O), IC5.4 (I0)
unnamed: IC3.1 (A14), JP2.1
unnamed: IC4.11 (O), IC5.5 (I1)
unnamed: IC5.3 (O), IC5.9 (I0)
unnamed: IC5.6 (O), IC5.10 (I1)
unnamed: IC4.1 (I0), J-CS0.2
unnamed: IC4.2 (I1), J-CS1.2
unnamed: IC4.4 (I0), J-CS2.2
unnamed: IC4.5 (I1), J-CS3.2
unnamed: IC4.9 (I0), J-CS4.2
unnamed: IC4.10 (I1), J-CS5.2
unnamed: IC4.12 (I0), J-CS6.2
unnamed: IC4.13 (I1), J-CS7.2
OE: IC1.8 (O), IC3.22 (!OE)
PHI0: IC1.4 (I0), IC1.10 (I1), U$1.21 (PHI0)
R/~W: IC1.9 (I0), IC1.12 (I0), IC1.13 (I1), U$1.24 (R/~W)
VCC: C1.2, C2.2, C3.2, C4.2, C5.2, IC1.14 (VCC), IC2.16 (VCC), IC3.28 (VCC), IC4.14 (VCC), IC5.14 (VCC), J-CS0.1, J-CS1.1, J-CS2.1, J-CS3.1, J-CS4.1, J-CS5.1, J-CS6.1, J-CS7.1, JP4.1, R1.2, U$1.18 (VCC)
WE: IC3.27 (!WE), JP4.2

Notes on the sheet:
BO6502

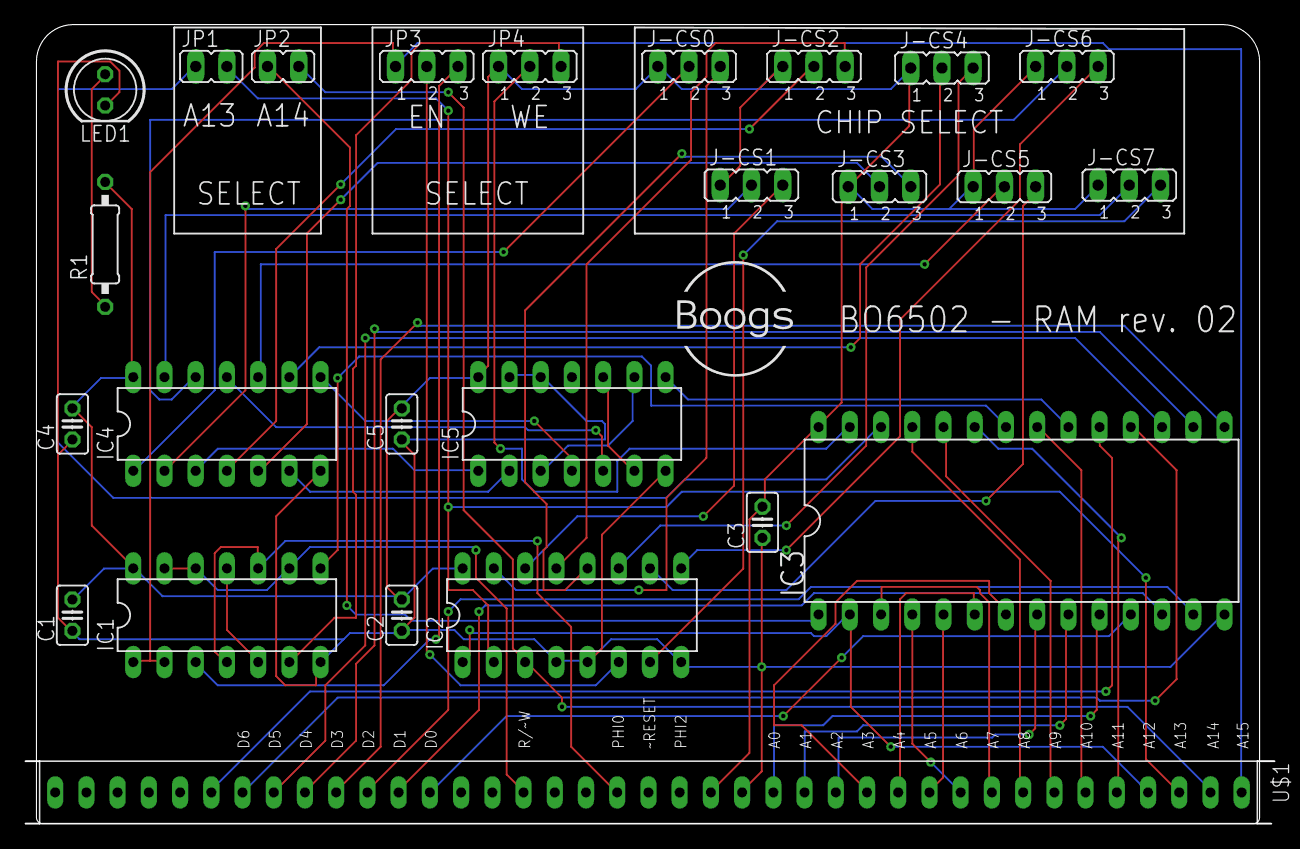
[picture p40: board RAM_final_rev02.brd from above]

Board: 2 copper layers, 101.6 x 65.0 mm, 25 parts (0 on the bottom side), 60 nets.

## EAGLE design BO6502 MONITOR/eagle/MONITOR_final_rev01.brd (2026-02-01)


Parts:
JP1: VCC_EN; JP1
U$1: BACKPLANE_39X; BP_39X
U$2: MEGA_DEVICE; MEGAOUTLINE

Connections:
A0: U$1.16 (A0), U$2.52
A1: U$1.15 (A1), U$2.50
A2: U$1.14 (A2), U$2.48
A3: U$1.13 (A3), U$2.46
A4: U$1.12 (A4), U$2.44
A5: U$1.11 (A5), U$2.42
A6: U$1.10 (A6), U$2.40
A7: U$1.9 (A7), U$2.38
A8: U$1.8 (A8), U$2.36
A9: U$1.7 (A9), U$2.34
A10: U$1.6 (A10), U$2.32
A11: U$1.5 (A11), U$2.30
A12: U$1.4 (A12), U$2.28
A13: U$1.3 (A13), U$2.26
A14: U$1.2 (A14), U$2.24
A15: U$1.1 (A15), U$2.22
D0: U$1.27 (D0), U$2.53
D1: U$1.28 (D1), U$2.51
D2: U$1.29 (D2), U$2.49
D3: U$1.30 (D3), U$2.47
D4: U$1.31 (D4), U$2.45
D5: U$1.32 (D5), U$2.43
D6: U$1.33 (D6), U$2.41
D7: U$1.34 (D7), U$2.39
GND: U$1.17 (GND), U$2.GND@2 (GND)
unnamed: JP1.2, U$2.5V
PHI0: U$1.21 (PHI0), U$2.2
R/~W: U$1.24 (R/~W), U$2.3
VCC: JP1.1, U$1.18 (VCC)

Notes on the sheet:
BO6502


Board: 2 copper layers, 101.6 x 65.0 mm, 3 parts (1 on the bottom side), 29 nets.

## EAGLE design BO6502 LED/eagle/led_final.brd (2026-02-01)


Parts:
C1, C2: 100n; C025-025X050
D1: SB140; DO41-10
IC2: 74AC138N; DIL16
LED1, LED2, LED3, LED4, LED5, LED6, LED7, LED8, LED9, LED10, LED11, LED12, LED13, LED14, LED15, LED16, LED17: RED; LED5MM
R1, R2, R3, R4, R5, R6, R7, R8, R9, R10, R11, R12, R13, R14, R15, R16, R17: 330; 0207/10
U1: 65C22; DIL40
U$1: BACKPLANE_39X; BP_39X

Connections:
A0: U1.38 (RS0), U$1.16 (A0)
A1: U1.37 (RS1), U$1.15 (A1)
A2: U1.36 (RS2), U$1.14 (A2)
A3: U1.35 (RS3), U$1.13 (A3)
A12: IC2.1 (A), U1.24 (CS1), U$1.4 (A12)
A13: IC2.2 (B), U$1.3 (A13)
A14: IC2.3 (C), U$1.2 (A14)
A15: IC2.6 (G1), U$1.1 (A15)
D0: U1.33 (D0), U$1.27 (D0)
D1: U1.32 (D1), U$1.28 (D1)
D2: U1.31 (D2), U$1.29 (D2)
D3: U1.30 (D3), U$1.30 (D3)
D4: U1.29 (D4), U$1.31 (D4)
D5: U1.28 (D5), U$1.32 (D5)
D6: U1.27 (D6), U$1.33 (D6)
D7: U1.26 (D7), U$1.34 (D7)
GND: C1.1, C2.1, IC2.4 (G2A), IC2.5 (G2B), IC2.8 (GND), LED1.K (C), LED2.K (C), LED3.K (C), LED4.K (C), LED5.K (C), LED6.K (C), LED7.K (C), LED8.K (C), LED9.K (C), LED10.K (C), LED11.K (C), LED12.K (C), LED13.K (C), LED14.K (C), LED15.K (C), LED16.K (C), LED17.K (C), U1.1 (GND), U$1.17 (GND)
unnamed: D1.C, U1.21 (~IRQ)
unnamed: LED2.A, R2.1
unnamed: LED3.A, R3.1
unnamed: LED1.A, R1.1
unnamed: LED4.A, R4.1
unnamed: LED5.A, R5.1
unnamed: LED6.A, R6.1
unnamed: LED7.A, R7.1
unnamed: LED8.A, R8.1
unnamed: LED9.A, R9.1
unnamed: LED10.A, R10.1
unnamed: LED11.A, R11.1
unnamed: LED12.A, R12.1
unnamed: LED13.A, R13.1
unnamed: LED14.A, R14.1
unnamed: LED15.A, R15.1
unnamed: LED16.A, R16.1
unnamed: LED17.A, R17.1
PA0: R9.2, U1.2 (PA0)
PA1: R8.2, U1.3 (PA1)
PA2: R7.2, U1.4 (PA2)
PA3: R6.2, U1.5 (PA3)
PA4: R5.2, U1.6 (PA4)
PA5: R4.2, U1.7 (PA5)
PA6: R3.2, U1.8 (PA6)
PA7: R2.2, U1.9 (PA7)
PB0: R17.2, U1.10 (PB0)
PB1: R16.2, U1.11 (PB1)
PB2: R15.2, U1.12 (PB2)
PB3: R14.2, U1.13 (PB3)
PB4: R13.2, U1.14 (PB4)
PB5: R12.2, U1.15 (PB5)
PB6: R11.2, U1.16 (PB6)
PB7: R10.2, U1.17 (PB7)
PHI0: U1.25 (PHI2), U$1.21 (PHI0)
R/~W: U1.22 (R/~W), U$1.24 (R/~W)
VCC: C1.2, C2.2, IC2.16 (VCC), R1.2, U1.20 (VCC), U$1.18 (VCC)
~CS2: IC2.10 (Y5), U1.23 (~CS2)
~IRQ: D1.A, U$1.22 (~IRQ)
~RESET: U1.34 (~RESET), U$1.20 (~RESET)

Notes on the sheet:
BO6502


Board: 2 copper layers, 101.3 x 65.0 mm, 40 parts (0 on the bottom side), 57 nets.

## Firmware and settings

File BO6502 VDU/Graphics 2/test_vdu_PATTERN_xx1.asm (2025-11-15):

;;;;;;;;;;;;;;;;;;;;;;;;;;;;;;;;;;;;;;;
;                                     ;
;      see pattern on screen          ;
;      Written in 6502 assembly       ;
;      05-11-25 by boogs              ;
;      moving                         ;
;      PERCORSO                       ;
;;;;;;;;;;;;;;;;;;;;;;;;;;;;;;;;;;;;;;;

VDP_INIT                 = $30
VDP_INIT_HI 	         = $31
ROW_VAR                  = $32     
COL_VAR                  = $33     
TEMP_MULT_LO             = $34     
TEMP_MULT_HI             = $35     
X_VIDEO_LO               = $36     
X_VIDEO_HI               = $37        

SPRITE_X_POS             = $38
SPRITE_Y_POS             = $39

VDP_INIT_A               = $40
VDP_INIT_HI_A 	         = $41


A_CURRENT_JOY         = $50 
A_PREV_JOY            = $51 
A_NEW_COMMANDS        = $52

PORTB_JOY = $d1A0        ;
PORTA_JOY = $d1A1        ;
DDRB_JOY  = $d1A2        ;
DDRA_JOY  = $d1A3        ;
ACR_JOY   = $d1AB

 .org $1000
VREG  = $B001                ;VDP REGISTER
VDATA = $B000                ;VDP RAM




VDP_PATTERN_TABLE_BASE  = $0000      ; PATTERN TABLE OK REG4      00-03
VDP_PATTERN_TABLE_BASE1 = $0800       
VDP_PATTERN_TABLE_BASE2 = $1000
VDP_SPRITE_TABLE_BASE   = $1800      ; SPRITE TABLE  OK REG6      03
VDP_COLOR_TABLE_BASE    = $2000      ; COLOR TABLE   OK REG3      80-FF
VDP_COLOR_TABLE_BASE1   = $2800
VDP_COLOR_TABLE_BASE2   = $3000
VDP_NAME_TABLE_BASE     = $3800      ; NAME TABLE    OK REG2      0E
VDP_SPRITE_ATT_BASE     = $3B00      ; SPRITE ATT    OK REG5      76
 

VDP_WRITE_VRAM_BIT     = %01000000  ; pattern of second vram address write: 01AAAAAA
VDP_REGISTER_BITS      = %10000000  ; pattern of second register write: 10000RRR

RESET:
  JSR VDP_SET_REGISTERS        ; Setting VDP register
  JSR CLEAR_VRAM
  JSR VDP_SETUP

start:  
  LDA #$02
  STA SPRITE_X_POS
  LDA #$37
  STA SPRITE_Y_POS
  JSR SAFE_WRITE_SPRITE_ATTRS 
 
LOOP:
    LDA PORTA_JOY      ; Carica A con lo stato attuale della Porta A del 6522
    STA A_CURRENT_JOY ; Salva lo stato attuale in una variabile temporanea
    EOR A_PREV_JOY    ; XOR (O Esclusivo): Mette a 1 i bit che SONO CAMBIATI
            
    AND A_CURRENT_JOY ; AND logico: Mantiene solo i bit che ORA sono a 1 
                    ; e che erano cambiati. Risultato: I pulsanti appena premuti

    STA A_NEW_COMMANDS ; Memorizza la mappa dei nuovi comandi

    AND #$01        
    BNE UP_JOY1
    lda A_NEW_COMMANDS
    AND #$02        
    BNE DW_JOY1
    lda A_NEW_COMMANDS
    AND #$04        
    BNE LF_JOY1
    lda A_NEW_COMMANDS
    AND #$08        
    BNE RG_JOY1
    JMP A_CONTINUE 
    
UP_JOY1:           ;Y-1
    DEC SPRITE_Y_POS
    JSR SAFE_WRITE_SPRITE_ATTRS ;JSR WRITE_SPRITE_ATTRS_FROM_VARS 
    JMP A_CONTINUE 
DW_JOY1:           ;Y+1
    INC SPRITE_Y_POS
    JSR SAFE_WRITE_SPRITE_ATTRS ;JSR WRITE_SPRITE_ATTRS_FROM_VARS 
    JMP A_CONTINUE 
LF_JOY1:            ;X-1    
    LDA SPRITE_X_POS
    CMP #$00
    BNE NOT_FIRST_COL1 
    LDA #$FF
    STA SPRITE_X_POS
    JMP NOT_FIRST_COL2
NOT_FIRST_COL1:    
    DEC SPRITE_X_POS
NOT_FIRST_COL2: 
    JSR SAFE_WRITE_SPRITE_ATTRS ;JSR WRITE_SPRITE_ATTRS_FROM_VARS 
    JMP A_CONTINUE 
RG_JOY1:            ;;X-1
    INC SPRITE_X_POS
    LDA SPRITE_X_POS
    CMP #$FF
    BNE NOT_LAST_COL 
    LDA #0
    STA SPRITE_X_POS
NOT_LAST_COL:
    JSR SAFE_WRITE_SPRITE_ATTRS ;JSR WRITE_SPRITE_ATTRS_FROM_VARS  

A_CONTINUE:
    LDA A_CURRENT_JOY 
    STA A_PREV_JOY    ; L'attuale diventa il "precedente" per la prossima volta
    
    JMP LOOP 
  ;JMP $fe00  

VDP_SETUP:
  JSR VDP_INITIALIZE_COLOR_TABLE
  JSR VDP_INITIALIZE_COLOR_TABLE1
  JSR VDP_INITIALIZE_COLOR_TABLE2
  JSR VDP_INITIALIZE_NAME_TABLE 
  JSR VDP_INITIALIZE_SPRITE_TABLE  
  JSR VDP_INITIALIZE_PATTERN_TABLE
  JSR VDP_INITIALIZE_PATTERN_TABLE1
  JSR VDP_INITIALIZE_PATTERN_TABLE2           
  RTS


VDP_INITIALIZE_PATTERN_TABLE:       
 PHA
 PHX
 LDA #<(VDP_PATTERN_TABLE_BASE)                      ; Byte 1 loading LSB Pattern Table Address
 STA VREG
 LDA #(VDP_WRITE_VRAM_BIT | >VDP_PATTERN_TABLE_BASE) ; Byte 2 loading MSB Pattern Table Address (combined
 STA VREG                                            ; with 0 1 A0 A1 A2 A3 A4 A5
 LDA #<VDP_PATTERNS                                  ; LOAD THE START ADDRESS OF THE PATTERNS TO ZERO PAGE
 STA VDP_INIT_A
 LDA #>VDP_PATTERNS
 STA VDP_INIT_HI_A
VDP_PATTERN_TABLE_LOOP: 
 LDA (VDP_INIT_A)                                    ; LOAD A WITH THE VALUE AT VDP_INIT
 STA VDATA                                           ; AND STORE IT TO VRAM
 LDA VDP_INIT_A                                      ; LOAD THE LOW BYTE OF VDP_INIT ADDRESS INTO A
 CLC                                                 ; CLEAR CARRY FLAG
 ADC #1                                              ; ADD 1, WITH CARRY
 STA VDP_INIT_A                                      ; STORE BACK INTO VDP_INIT
 LDA #0                                              ; LOAD A WITH 0
 ADC VDP_INIT_HI_A                                   ; ADD WITH THE CARRY FLAG TO THE HIGH ADDRESS
 STA VDP_INIT_HI_A                                   ; AND STORE THAT BACK INTO THE HIGH BYTE
 CMP #>VDP_END_PATTERNS                              ; COMPARE IF WE'RE AT THE END OF THE PATTERNS
 BNE VDP_PATTERN_TABLE_LOOP                          ; IF NOT, LOOP AGAIN
 LDA VDP_INIT_A                                      ; COMPARE THE LOW BYTE
 CMP #<VDP_END_PATTERNS
 BNE VDP_PATTERN_TABLE_LOOP                          ; IF NOT EQUAL, LOOP AGAIN
 PLX
 PLA
 RTS
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

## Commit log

2026-01-31 Update README to clarify voltage regulator details
2026-01-31 few changes
    [backplate_final_rev02.brd, backplate_final_rev02.sch]
2026-01-31 main changes
    [backplate5V_final_rev01.brd, backplate5V_final_rev01.sch]
2026-02-01 many changes
    [CPU_final_rev02.brd, CPU_final_rev02.sch]
2026-02-01 Changes images pcb color
2026-02-01 Audio changes
    [AUDIO_005.brd, AUDIO_005.sch]
2026-02-01 Add KEYB PCB
    [KEYb_final-rev01.brd, KEYb_final-rev01.sch]
2026-02-01 PCB LEDs changes
    [led_final.brd, led_final.sch]
2026-02-01 Add monitor PCB
    [MONITOR_final_rev01.brd, MONITOR_final_rev01.sch]
2026-02-01 add RAM PCB
    [RAM_final_rev02.brd, RAM_final_rev02.sch]
2026-02-01 Add RESET PCB
    [reset_final_rev01.brd, reset_final_rev01.sch]
2026-02-01 add rom PCBs
    [ROM24k_final_rev01.brd, ROM24k_final_rev01.sch, ROM_final_rev01.brd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]
2026-02-02 add SDCard PCB
    [SDcard_final_rev02.brd, SDcard_final_rev02.sch]
2026-02-02 add SERIAL PCB
    [Serial_final_rev03.brd, Serial_final_rev03.sch]
2026-02-02 add VDU PCB
    [VDU_TMS_final_rev01.brd, VDU_TMS_final_rev01.sch]

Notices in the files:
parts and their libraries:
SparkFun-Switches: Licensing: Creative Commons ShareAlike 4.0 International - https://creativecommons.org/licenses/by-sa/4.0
